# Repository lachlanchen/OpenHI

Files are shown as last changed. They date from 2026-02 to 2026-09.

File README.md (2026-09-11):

[English](README.md) · [العربية](i18n/README.ar.md) · [Español](i18n/README.es.md) · [Français](i18n/README.fr.md) · [日本語](i18n/README.ja.md) · [한국어](i18n/README.ko.md) · [Tiếng Việt](i18n/README.vi.md) · [中文 (简体)](i18n/README.zh-Hans.md) · [中文（繁體）](i18n/README.zh-Hant.md) · [Deutsch](i18n/README.de.md) · [Русский](i18n/README.ru.md)

# Self-Calibrated Neuromorphic Hyperspectral Imaging (OpenHI)















> [!NOTE]
> i18n status in this checkout: all linked translation files are present under `i18n/` (`ar`, `de`, `es`, `fr`, `ja`, `ko`, `ru`, `vi`, `zh-Hans`, `zh-Hant`) with English as the root canonical README.

A comprehensive pipeline for reconstructing spectra from event cameras with dispersed light illumination (e.g., diffraction grating). The system records intensity change events $e = (x, y, t, p)$ where $p \in \{-1, +1\}$ indicates polarity of log-intensity change, and automatically infers scan timing and calibration metadata ("auto info") directly from the event stream.

> [!IMPORTANT]
> This README is the canonical technical source for the repository root. Localized files under `i18n/` should mirror section and header evolution while keeping exactly one language-options line at the top.

<p align="center">
  Device setup
  Acquisition GUI
</p>

*Left: modular transmission microscope with a motorised grating illumination arm and vertical detection stack. Right: data-acquisition GUI used to monitor segmentation, compensation, and reconstructions in real time.*

## Quick Access

| Need | Jump to |
|---|---|
| Start in ~5 minutes | [Quick Start (5-Min Path) ⚡](#quick-start-5-min-path) |
| Run the full pipeline wrapper | [`scripts/run_scan_pipeline.sh`](scripts/run_scan_pipeline.sh) |
| Understand script flow | [Overview 🔭](#overview), [Core Scripts 🧠](#core-scripts) |
| Tune parameters | [Configuration 🎛️](#configuration), [Configuration Examples 🧩](#configuration-examples) |
| Use GUI tools | [Additional Tools 🛠️](#additional-tools) |
| Hardware docs (BOM, PCB, 3D, firmware) | [Repository Map 🗺️](#repository-map) |
| Inspect a frozen software-stage run | [Fixture, environment, log, output, and hashes](https://lazying.art/openhi-reproducibility/sample-report/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) |
| Test one software stage on your setup | [USD 500 reproducibility sprint](https://lazying.art/openhi-reproducibility/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) |
| Multilingual maintenance rules | [Internationalization 🌍](#internationalization) |
| Sponsor and support links | [Support / Sponsor 💖](#support--sponsor) |

## At a Glance

| Item | Details |
|---|---|
| Core idea | Self-calibrated hyperspectral derivative imaging from event streams |
| Main stages | `segment_robust_fixed.py` -> `compensate_multiwindow_train_saved_params.py` -> visualization scripts |
| Hardware docs in repo | `3D/`, `PCB/`, `firmware/`, `BOM/` |
| Desktop tools | `scan_compensation_gui_cloud.py`, `ImagingGUI/DualCamera_separate_transform.py` |
| Canonical paper | [Optica article (DOI: 10.1364/OPTICA.585766)](https://doi.org/10.1364/OPTICA.585766) |
| i18n in this checkout | `README.ar.md`, `README.de.md`, `README.es.md`, `README.fr.md`, `README.ja.md`, `README.ko.md`, `README.ru.md`, `README.vi.md`, `README.zh-Hans.md`, `README.zh-Hant.md` |

### Compatibility Snapshot

| Area | Current repository reality |
|---|---|
| Python baseline | `3.9+` recommended (some `ImagingGUI/` utilities note `3.10+`) |
| Main pipeline launcher | `scripts/run_scan_pipeline.sh` |
| Core training script | `compensate_multiwindow_train_saved_params.py` |
| Hardware collateral | Present under `3D/`, `PCB/`, `BOM/`, `firmware/` |
| Multilingual docs | `i18n/` contains all 10 linked language files |

> [!TIP]
> Ask about the core development kit (excluding camera, tube lens, and optical table) for the paper [Self-calibrated neuromorphic hyperspectral derivative imaging](https://doi.org/10.1364/OPTICA.585766) published in Optica:
> - https://lazying.art/openhi-kit.html
>
> Evaluating the software first? The [OpenHI Software Reproducibility Sprint](https://lazying.art/openhi-reproducibility/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) tests one named pipeline stage on one existing workstation and rights-cleared dataset before a hardware decision.

## Contents

- [Quick Access ⚡](#quick-access)
- [At a Glance 📌](#at-a-glance)
- [Overview 🔭](#overview)
- [Features ✨](#features)
- [Repository Map 🗺️](#repository-map)
- [Project Structure 📁](#project-structure)
- [Quick Start (5-Min Path) ⚡](#quick-start-5-min-path)
- [Prerequisites 🧰](#prerequisites)
- [Installation ⚙️](#installation)
- [Usage 🚀](#usage)
- [Internationalization 🌍](#internationalization)
- [Configuration 🎛️](#configuration)
- [Examples 🧪](#examples)
- [Bill of Materials (Core Module) 🧾](#bill-of-materials-core-module)
- [Core Scripts 🧠](#core-scripts)
- [Additional Tools 🛠️](#additional-tools)
- [Turbo Multi-Scan Compensation ⚡](#turbo-multi-scan-compensation)
- [Parameter Management 💾](#parameter-management)
- [Memory Optimization 🧱](#memory-optimization)
- [Output Structure 📦](#output-structure)
- [Configuration Examples 🧩](#configuration-examples)
- [Wavelength Mapping 🌈](#wavelength-mapping)
- [Tips and Best Practices ✅](#tips-and-best-practices)
- [Development Notes 🧭](#development-notes)
- [Troubleshooting 🩺](#troubleshooting)
- [Roadmap 🛣️](#roadmap)
- [Citation 📎](#citation)
- [Acknowledgements 🙏](#acknowledgements)
- [License 📄](#license)
- [Contributing 🤝](#contributing)
- [Support / Sponsor 💖](#support--sponsor)

## Overview

When illumination sweeps across wavelengths over time, the event stream encodes a temporal derivative of the underlying spectrum along the dispersion axis.

```text
RAW event recording
   -> scan timing segmentation (F/B passes)
   -> multi-window time-warp compensation
   -> frame/cumulative/wavelength diagnostics
```

This pipeline provides three main stages:

| Stage | Purpose | Primary script(s) |
|---|---|---|
| 1. Segment | Find scan timing and split recordings into forward/backward passes | `segment_robust_fixed.py` |
| 2. Compensate | Estimate piecewise-linear time-warp to remove scan-induced temporal tilt | `compensate_multiwindow_train_saved_params.py` |
| 3. Visualize | Overlay learned boundaries and compare original vs. compensated time-binned frames | `visualize_boundaries_and_frames.py`, `visualize_cumulative_compare.py` |

The repository also includes hardware assets, acquisition GUI code, and archival experiment branches under `versions/`.

### Pipeline Legend

| Icon | Meaning |
|---|---|
| 🧩 | Segmentation and scan splitting |
| 🧠 | Compensation and parameter learning |
| 🖼️ | Visual diagnostics and output inspection |
| 🌈 | Wavelength mapping and spectral rendering |

### Scope and Assumptions

- This repository is research-oriented and includes active scripts plus archival experiments and results.
- Commands in this README assume execution from repository root unless otherwise noted.
- Several optional workflows depend on external SDKs and local datasets that are not bundled here.
- If a command mentions a historical path that no longer exists, prefer the updated root scripts and comparisons paths documented in this README.

## Features

- End-to-end RAW-to-spectrum event processing workflow.
- Auto/manual scan period detection and forward/backward segmentation.
- Multi-window compensation with trainable/fixed parameter modes.
- Parameter save/load in `NPZ`, `JSON`, and `CSV`.
- Multi-scan merge workflow for faster training iterations (`compensate_multiwindow_turbo.py`).
- Visualization suite for boundaries, binned frames, cumulative curves, and weighted diagnostics.
- Hardware documentation: BOM, PCB, 3D parts, firmware notes.
- Acquisition utilities for synchronized event/frame camera setups.

| Category | Included capabilities |
|---|---|
| Signal processing | Segmentation, period detection, time-warp compensation |
| Optimization | Trainable/fixed parameters, smoothness controls, chunked training |
| Outputs | Visual overlays, cumulative comparisons, wavelength-mapped diagnostics |
| Platform assets | Hardware design files, firmware notes, GUI tooling, historical archives |

## Repository Map

Key hardware assets are kept alongside the code for quick access:

| Area | Path |
|---|---|
| 3D-printed parts | [`3D/`](3D/) |
| PCB layouts | [`PCB/`](PCB/) |
| Microcontroller firmware | [`firmware/`](firmware/) |
| Acquisition UI (desktop) | [`ImagingGUI/`](ImagingGUI/) |
| Experiment/data references | [`comparisons/reference_spectrum_2835/`](comparisons/reference_spectrum_2835/), [`comparisons/reference_spectrum_lumileds/`](comparisons/reference_spectrum_lumileds/), [`references/`](references/) |
| Alignment analysis | [`comparisons/align_background_vs_reference_code/`](comparisons/align_background_vs_reference_code/), [`comparisons/alignment_configs/`](comparisons/alignment_configs/) |

## Project Structure

```text
OpenHI/
├── README.md
├── QUICKSTART.md
├── LICENSE
├── versions.md
├── 3D/
├── BOM/
├── PCB/
├── firmware/
├── ImagingGUI/
├── scripts/
├── segment_robust_fixed.py
├── compensate_multiwindow_train_saved_params.py
├── compensate_multiwindow_turbo.py
├── compensate_multiwindow*.py
├── visualize_boundaries_and_frames.py
├── visualize_cumulative_compare.py
├── visualize_cumulative_weighted.py
├── scan_compensation_gui_cloud.py
├── show_envi_spectrum_gui.py
├── simple_raw_reader.py
├── comparisons/align_background_vs_reference_code/
├── align_data_vs_filter_code/
├── comparisons/alignment_configs/
├── versions/05_archive_code_variants/
├── comparisons/outputs_root/
├── comparisons/reference_filters/
├── comparisons/reference_spectrum_2835/
├── comparisons/reference_spectrum_lumileds/
├── references/
├── i18n/
└── versions/
```

## Quick Start (5-Min Path)

If your environment is already prepared and your dataset folder contains a `*event*.raw` file:

```bash
scripts/run_scan_pipeline.sh /path/to/dataset_dir
```

To force a specific RAW file:

```bash
scripts/run_scan_pipeline.sh /path/to/dataset_dir /path/to/recording_event.raw
```

This wrapper runs segmentation, compensation training, and visualization using repository-default script paths and CLI flags.

> [!TIP]
> For first validation, run the wrapper on one dataset directory, then inspect the generated segment NPZ and visualization outputs before tuning `PIPELINE_*` variables.

## Prerequisites

- Python 3.9+ (Python 3.10+ for some GUI tooling under `ImagingGUI/`).
- Core Python packages: `numpy`, `torch`, `matplotlib`.
- Optional but common: `opencv-python`, `pillow`, `cellpose`.
- Metavision SDK / Python bindings for RAW event reading workflows (`simple_raw_reader.py`, segmentation from RAW).
- CUDA-enabled PyTorch is recommended for faster optimization.
- RAW recordings and/or segmented NPZ files available locally.

## Installation

No locked environment file is currently provided at repository root. Suggested setup:

```bash
# create and activate a virtual environment or conda env
python -m venv .venv
source .venv/bin/activate

# install core dependencies
pip install numpy matplotlib torch

# optional tools often used in this repository
pip install opencv-python pillow
# pip install cellpose
```

If using Git hooks for large-file hygiene:

```bash
bash scripts/setup_hooks.sh
```

Recommended quick sanity checks:

```bash
python -c "import numpy, torch, matplotlib; print('core deps ok')"
python -c "import torch; print('cuda:', torch.cuda.is_available())"
```

## Usage

### Basic Workflow (current root scripts)

```bash
# 1. Segment RAW into 6 scans (Forward/Backward)
python segment_robust_fixed.py \
  data/recording.raw \
  --segment_events \
  --output_dir data/segments/

# 2. Train multi-window compensation
python compensate_multiwindow_train_saved_params.py \
  data/segments/Scan_1_Forward_events.npz \
  --bin_width 50000 \
  --visualize --plot_params --a_trainable \
  --iterations 1000

# 3. Visualize results with boundaries
python visualize_boundaries_and_frames.py \
  data/segments/Scan_1_Forward_events.npz

# 4. Compare cumulative vs multi-bin means
python visualize_cumulative_compare.py \
  data/segments/Scan_1_Forward_events.npz \
  --sensor_width 1280 --sensor_height 720
```

### One-command convenience wrapper

```bash
scripts/run_scan_pipeline.sh /path/to/dataset_dir [raw_file]
```

### Command-to-Output Reference

| Step | Command entrypoint | Primary output |
|---|---|---|
| Segment scans | `segment_robust_fixed.py` | `*_segments/Scan_*_{Forward,Backward}_events.npz` |
| Train compensation | `compensate_multiwindow_train_saved_params.py` | `*learned_params_n*.{npz,json,csv}` plus diagnostics |
| Boundary and frame diagnostics | `visualize_boundaries_and_frames.py` | timestamped visualization folder with overlays and bins |
| Cumulative diagnostics | `visualize_cumulative_compare.py`, `visualize_cumulative_weighted.py` | cumulative and statistical plots for scan quality checks |
| Convenience wrapper | `scripts/run_scan_pipeline.sh` | end-to-end segmentation, training, and visualization |

### Minimal Smoke Test

Use this when you want to validate script wiring on an existing segment NPZ before a longer optimization run:

```bash
python visualize_boundaries_and_frames.py /path/to/Scan_1_Forward_events.npz \
  --sample_rate 0.05 --sensor_width 1280 --sensor_height 720

python visualize_cumulative_compare.py /path/to/Scan_1_Forward_events.npz \
  --sensor_width 1280 --sensor_height 720
```

Environment knobs supported by `scripts/run_scan_pipeline.sh`:

| Variable | Default | Purpose |
|---|---:|---|
| `PIPELINE_ACTIVITY_FRACTION` | `0.90` | Active event window fraction |
| `PIPELINE_BIN_WIDTH` | `50000` | Training bin width in microseconds |
| `PIPELINE_SENSOR_WIDTH` | `1280` | Sensor width for visualization |
| `PIPELINE_SENSOR_HEIGHT` | `720` | Sensor height for visualization |
| `PIPELINE_SAMPLE_RATE` | `0.10` | Event sampling fraction for plotting |
| `PIPELINE_TIME_BIN_US` | `1000` | Segmentation activity-bin size |
| `PIPELINE_SEGMENT_PATTERN` | `Scan_1_Forward_events.npz` | Segment file pattern for downstream scripts |

## Internationalization

The repository uses a single language-options line at the top of each README to avoid duplicated language bars.

Currently available translated files in `i18n/`:

- `README.ar.md`
- `README.es.md`
- `README.fr.md`
- `README.ja.md`
- `README.ko.md`

| Language link in nav | File in `i18n/` | Status |
|---|---|---|

Planned language links are intentionally preserved in the top navigation for forward compatibility.

## Configuration

Important CLI controls used across scripts:

### Segmentation (`segment_robust_fixed.py`)

- `--time_bin_us`: activity bin size in microseconds.
- `--round_trip_period`: manual period (default `1688` bins).
- `--auto_calculate_period`: period via autocorrelation.
- `--activity_fraction`: active event window fraction.
- `--manual_start_shift_ms`: manual scan start offset.

### Compensation (`compensate_multiwindow_train_saved_params.py`)

- `--num_params` (default `13`), `--temperature` (default `5000`).
- `--a_trainable` / `--a_fixed`, `--b_trainable` / `--b_fixed`, `--boundary_trainable`.
- `--a_default`, `--b_default`.
- `--iterations`, `--learning_rate`, `--smoothness_weight`.
- `--chunk_size` for memory control.
- `--load_params` to reuse learned parameters.

### Visualization

- `visualize_boundaries_and_frames.py`: `--sample_rate`, `--wavelength_min`, `--wavelength_max`, sensor size args.
- `visualize_cumulative_compare.py`: sensor size, `--output_dir`, `--sample_label`.
- `visualize_cumulative_weighted.py`: polarity scales, `--step_us`, `--auto_scale`, `--exp`, `--no_comp`.

## Examples

### Quick start dataset-style commands (from `QUICKSTART.md`)

```bash
python segment_robust_fixed.py \
  led_12v_no_acc_glass/glass/sync_recording_12v_led_no_acc_blank_event_20250804_232556.raw \
  --segment_events \
  --output_dir led_12v_no_acc_glass/glass/

python compensate_multiwindow_train_saved_params.py \
  led_12v_no_acc_glass/glass/sync_recording_12v_led_no_acc_blank_event_20250804_232556_segments/Scan_1_Forward_events.npz \
  --bin_width 50000 \
  --visualize --plot_params --a_trainable \
  --iterations 1000 \
  --b_default 0 \
  --smoothness_weight 0.001

python visualize_boundaries_and_frames.py \
  led_12v_no_acc_glass/glass/sync_recording_12v_led_no_acc_blank_event_20250804_232556_segments/Scan_1_Forward_events.npz
```

### Legacy helper commands retained from historical workflows

```bash
python scanning_alignment_visualization_save.py \
  led_12v_no_acc_glass/glass/sync_recording_12v_led_no_acc_blank_event_20250804_232556_segments/Scan_1_Forward_events.npz \
  --output_dir led_12v_no_acc_glass/glass/sync_recording_12v_led_no_acc_blank_event_20250804_232556_segments/FIXED_visualization

python scanning_alignment_visualization_cumulative_compare.py \
  led_12v_no_acc_glass/glass/sync_recording_12v_led_no_acc_blank_event_20250804_232556_segments/Scan_1_Forward_events.npz \
  --sensor_width 1280 --sensor_height 720 \
  --output_dir led_12v_no_acc_glass/glass/sync_recording_12v_led_no_acc_blank_event_20250804_232556_segments/cumulative_vs_bin2ms \
  --sample_label "led_12v_no_acc_glass Scan_1_Forward"
```

These legacy commands are intentionally preserved for compatibility context; in this checkout, use current root scripts where possible.

### Turbo multi-scan training

```bash
python compensate_multiwindow_turbo.py \
  --segments-dir path/to/your_segments \
  --include all --sort name \
  --bin-width 5000 \
  -- --a_trainable --iterations 1000 --smoothness_weight 0.001 --chunk_size 250000 --visualize --plot_params
```

### Reuse learned parameters (skip retraining)

```bash
python compensate_multiwindow_train_saved_params.py segment.npz \
  --load_params learned_params.npz
```

## Bill of Materials (Core Module)

See [`BOM/core_module.md`](BOM/core_module.md) for the full table with links and notes.

### Table S2. Acquisition Time and Cost Comparison Between the Proposed Event-Driven System and a Reference Hyperspectral Camera

| Parameter | Ours | Reference camera |
|---|---|---|
| Acquisition time | ∼585 ms per scan | 300 s per scan |
| Data volume | 18.5 MB | 138 MB |
| Approx. price | ∼3000 USD | 14 000 USD |

### Table S3. Bill of Materials for the Core Scanning Illumination Module
(Excluding event camera and optional 4f validation optics)

| Component | Notes | Cost (USD) | Taobao Link |
|---|---|---:|---|
| Motion control | NEMA42 + TB6600 + Arduino Uno | 15.00 | https://e.tb.cn/h.7FHgkEvoo6tpKTo?tk=QYRFUPRqazE |
| Optics (grating) | Diffraction grating (education grade) | 3.47 | https://e.tb.cn/h.7Fhj16MkrSDHNnE?tk=3Q8dUPRouNw |
| Illumination | 2835 LED (6 CNY / 10 pcs; 0.6 CNY used) | 0.08 | https://e.tb.cn/h.7uubHIVL5diILHl?tk=tzTAUPRr14K |
| Reflector | Folding mirror | 6.25 | https://e.tb.cn/h.7uu1rNNSbgVdS31?tk=PqsxUPRHb32 |
| Electronics | LED PCB (CNY/board; min order 5 pcs) | 1.67 |  |
| Limit switches | Optional, 2 × 8.07 CNY | 2.24 | https://e.tb.cn/h.7FHEKbcgJmc2Ll1?tk=I4FRUP8diRE |
| 3D printing | One-third PLA filament spool (covers all printed parts) | 5.09 | https://e.tb.cn/h.7FhOVWX7SLHvNNf?tk=kOcQUPRJsbo |
| Lens | Plano-convex lens (25.4 mm, 350–700 nm AR) |  | https://e.tb.cn/h.7FSePNYhqt7ITbh?tk=tH8ZUP8i3cC |
| Total | core module | **33.99** |  |

## Core Scripts

### 1. Segmentation: `segment_robust_fixed.py`

**Goal**: Extract scan timing from raw events and slice into 6 one-way scans (F, B, F, B, F, B).

**Mathematical Description**:

- **Activity signal** (events binned with $\Delta t = 1000~\mu\text{s}$):
  $$a[n] = \left|\{ i \mid t_{\min} + n\Delta t \le t_i < t_{\min} + (n+1)\Delta t \}\right|.$$

- **Active window detection**: find the smallest contiguous window containing $80\%$ of events.

- **Period estimation**: autocorrelation or manual period (default: $1688$ bins).

- **Reverse-correlation** (timing structure):
  $$R[k] = \sum_{n} a[n]\, a_{\text{rev}}[n+k]$$
  with
  $$a_{\text{rev}}[n] = a[N-1-n].$$

**Usage**:

```bash
# Automatic period detection
python segment_robust_fixed.py recording.raw --segment_events --output_dir segments/

# Manual period (fixed 1688 bins)
python segment_robust_fixed.py recording.raw --segment_events --round_trip_period 1688
```

**Arguments**:

- `--segment_events`: Save individual scan segments as NPZ files.
- `--round_trip_period 1688`: Use manual period (default).
- `--auto_calculate_period`: Override manual period with autocorrelation.
- `--activity_fraction 0.80`: Fraction of events for active region.
- `--max_iterations 2`: Refinement iterations.

### 2. Compensation: `compensate_multiwindow_train_saved_params.py`

**Goal**: Learn time-warp parameters to remove scan-induced temporal shear using multi-window piecewise-linear compensation.

**Mathematical Description**:

- **Boundary surfaces**:
  $$T_i(x, y) = a_i x + b_i y + c_i,\quad i=0,\ldots,M-1.$$

- **Soft window memberships**:
  $$m_i = \sigma\!\Big(\frac{t - T_i}{\tau}\Big)\,\sigma\!\Big(\frac{T_{i+1} - t}{\tau}\Big),\qquad w_i = \frac{m_i}{\sum_j m_j + \varepsilon}.$$

- **Interpolated slopes (optional)**:
  $$\alpha_i = \frac{t - T_i}{T_{i+1} - T_i},\quad a_i' = (1-\alpha_i)a_i + \alpha_i a_{i+1},\quad b_i' = (1-\alpha_i)b_i + \alpha_i b_{i+1}.$$

- **Time warp**:
  $$\Delta t(x,y,t) = \sum_i w_i (\tilde{a}_i x + \tilde{b}_i y),\qquad t' = t - \Delta t(x,y,t).$$

- **Loss**: variance minimization of time-binned frames with smoothness regularization on parameters.

**Usage**:

```bash
# Train with a-parameters trainable, b fixed
python compensate_multiwindow_train_saved_params.py segment.npz \
  --bin_width 50000 --a_trainable --b_default -76.0 \
  --iterations 1000 --smoothness_weight 0.001

# Load pre-trained parameters
python compensate_multiwindow_train_saved_params.py segment.npz \
  --load_params learned_params.npz
```

**Key Arguments**:

- `--a_trainable` / `--a_fixed`: Control a-parameter training (default: fixed).
- `--b_trainable` / `--b_fixed`: Control b-parameter training (default: trainable).
- `--num_params 13`: Number of boundary parameters.
- `--temperature 5000`: Sigmoid temperature for soft windows.
- `--smoothness_weight 0.001`: Regularization weight.
- `--load_params file.npz`: Load saved parameters.
- `--chunk_size 250000`: Memory-efficient processing chunk size.

### 3. Visualization: `visualize_boundaries_and_frames.py`

**Goal**: Display learned parameters and show qualitative improvements.

**Features**:

- Parameter overlays on $x\text{–}t$ and $y\text{–}t$ projections.
- Time-binned frame comparisons (original vs. compensated).
- Sliding window analysis (50 ms and 2 ms bins).
- Wavelength mapping for spectral visualization.

**Usage**:

```bash
python visualize_boundaries_and_frames.py segment.npz \
  --sample_rate 0.1 --wavelength_min 380 --wavelength_max 680
```

### 4. Cumulative Comparison: `visualize_cumulative_compare.py`

**Goal**: Compare cumulative 2 ms-step means with sliding bin means.

**Mathematical Description**:

- **Cumulative means**:
  $$F(T) = \frac{1}{HW}\sum_{t < T}\text{events}(t).$$

- **Sliding means**: event counts in $[T-\Delta,\,T)$ divided by $H \times W$.

- **Relationship** (finite-difference derivative):
  $$\Delta F(T) \approx \frac{F(T) - F(T-\Delta)}{\Delta}.$$

**Usage**:

```bash
python visualize_cumulative_compare.py segment.npz \
  --sensor_width 1280 --sensor_height 720 \
  --sample_label "My Dataset"
```

## Additional Tools

### GUI Application: `scan_compensation_gui_cloud.py`

Complete GUI for scan compensation with 3D spectral visualization.

**Features**:

- Interactive parameter tuning.
- Real-time optimization progress.
- 3D wavelength-mapped visualization.
- Export results and parameters.

**Usage**:

```bash
python scan_compensation_gui_cloud.py
```

### Dual Camera System (current path)

Synchronized recording system for event and frame cameras:

- `ImagingGUI/DualCamera_separate_transform.py`

**Features**:

- Simultaneous event and frame recording.
- Real-time preview with transformations.
- Always-on-top window controls.
- Parameter adjustment during recording.

### Arduino Motor Control (legacy path reference retained)

The original README referenced this firmware sketch path:

- `rotor/step42_with_key_int/step42_with_key_int.ino`

Current repository layout includes firmware notes at:

- `firmware/README.md`

This path mismatch is preserved here intentionally; if you have the rotor sketch folders in another branch/local checkout, keep using those paths.

Legacy documented capabilities of this sketch include:

- Precise angle control with microstepping.
- Acceleration/deceleration profiles.
- Limit switch integration.
- Auto-centering functionality.

## Turbo Multi-Scan Compensation

When you have multiple one-way scans (Forward/Backward) of the same sweep, you can merge them and run the proven trainer on a single combined event stream using `compensate_multiwindow_turbo.py`.

### What it does

- Accepts one segment, an explicit list, or a whole segments directory.
- For Backward scans, flips polarity and reverses time before merging:
- If polarity `p ∈ {0,1}`: `p := 1 − p`; then reverse time within the scan.
- If polarity `p ∈ {−1,1}`: `p := −p`; then reverse time within the scan.
- Concatenates scans on a continuous timeline (with a `1 μs` gap between scans) and calls `compensate_multiwindow_train_saved_params.py` under the hood.

### Usage

```bash
# Merge all scans (Forward+Backward) from a segments folder and train at 5 ms
python compensate_multiwindow_turbo.py \
  --segments-dir path/to/.../_segments \
  --include all --sort name \
  --bin-width 5000 \
  -- --a_trainable --iterations 1000 --smoothness_weight 0.001 --chunk_size 250000 --visualize --plot_params

# Reuse learned params and just render at 10 ms (fast, no training)
python compensate_multiwindow_turbo.py \
  --segments-dir path/to/.../_segments \
  --include all --sort time \
  --bin-width 10000 \
  --load-params path/to/learned_params.npz \
  -- --visualize --plot_params

# Only Forward scans
python compensate_multiwindow_turbo.py \
  --segments-dir path/to/.../_segments \
  --include forward --sort time \
  --bin-width 5000 \
  -- --a_trainable --iterations 1000 --smoothness_weight 0.001 --chunk_size 250000
```

### Options

- `--segment`, `--segments`, `--segments-dir`: choose your input set.
- `--include {all|forward|backward}`: filter by scan direction.
- `--sort {name|time}`: natural filename order or NPZ `start_time` order.
- `--bin-width <μs>`: forwarded to the base trainer.
- `--load-params`: reuse saved parameters (skip training and regenerate outputs quickly at new bin widths).
- `--extra ...` after `--`: any additional flags are forwarded to the base trainer.

### Speed scaling tip

If your scan is `N×` faster than baseline, reduce `--bin-width` by the same factor (e.g., baseline `50 ms` -> `10×` faster -> `5 ms`: `--bin-width 5000`). You can train once (e.g., `5 ms`), then use `--load-params` to quickly regenerate results at `10 ms` without retraining.

## Parameter Management

The system supports comprehensive parameter save/load functionality.

### Save Formats

- **NPZ**: Binary format for fast loading.
- **JSON**: Human-readable with metadata.
- **CSV**: Excel-compatible for manual inspection.

### Parameter Loading

```bash
# Load any supported format
python compensate_multiwindow_train_saved_params.py segment.npz \
  --load_params learned_params.npz
# or --load_params learned_params.json
# or --load_params learned_params.csv
```

### Parameter Files

Files are automatically named with parameter count, such as: `*_learned_params_n13.*`.

## Memory Optimization

The system uses chunked processing throughout:

| Item | Detail |
|---|---|
| Chunk Size | Default `250000` events (configurable) |
| Memory Efficient | Processes large datasets without GPU overflow |
| Unified Variance | Maintains proper gradient flow for learning |
| Progress Tracking | Real-time processing updates |

## Output Structure

```text
project/
├── data/
│   ├── recording.raw                    # Original RAW file
│   ├── recording_segments/              # Segmented scans
│   │   ├── Scan_1_Forward_events.npz
│   │   ├── Scan_2_Backward_events.npz
│   │   └── ...
│   ├── learned_params_n13.npz          # Trained parameters
│   ├── learned_params_n13.json
│   ├── learned_params_n13.csv
│   └── visualization_20240115_143022/  # Results
│       ├── events_with_params.png
│       ├── sliding_frames_*.npz
│       ├── frame_means_wavelength.png
│       └── time_binned_frames/         # Individual frames
```

## Configuration Examples

### High-Precision Compensation

```bash
python compensate_multiwindow_train_saved_params.py segment.npz \
  --num_params 21 --temperature 3000 --iterations 2000 \
  --a_trainable --b_trainable --boundary_trainable \
  --smoothness_weight 0.0001 --chunk_size 100000
```

### Fast Processing

```bash
python compensate_multiwindow_train_saved_params.py segment.npz \
  --num_params 7 --iterations 500 --chunk_size 500000 \
  --a_fixed --b_default -76.0
```

### Memory Constrained

```bash
python compensate_multiwindow_train_saved_params.py segment.npz \
  --chunk_size 50000 --bin_width 100000
```

## Wavelength Mapping

The system supports spectral visualization by mapping temporal evolution to wavelength:

```python
# Linear mapping: time -> wavelength
wavelength = wavelength_min + (t_normalized / t_max) * (wavelength_max - wavelength_min)
```

**Default Range**: $380\text{–}680~\text{nm}$ (configurable).

## Tips and Best Practices

### Parameter Selection

- **Microstepping**: Use `32×` for smooth motion (Arduino).
- **Bin Width**: Start with `50 ms` for optimization, `2 ms` for analysis.
- **Temperature**: Higher values (around `5000`) for smoother boundaries.
- **Smoothness**: `0.001` provides good regularization.

### Memory Management

- **GPU Memory**: Use chunked processing with appropriate chunk size.
- **Event Count**: `> 10^6` events recommended for stable learning.
- **Iterations**: `1000` iterations usually sufficient.

### File Organization

- Keep RAW files and segments in the same directory.
- Parameter files are auto-detected by naming convention.
- Use descriptive filename prefixes for organized output.

## Development Notes

- `versions.md` describes historical project eras and migration rationale.
- `.githooks/pre-commit` blocks oversized/binary commits and non-code/doc file types.
- `scripts/setup_hooks.sh` sets `core.hooksPath` to `.githooks`.
- `versions/05_archive_code_variants/` stores older script variants to keep root-level tooling focused.

Known documentation drift (preserved intentionally for backward compatibility context):

- Some older docs mention `sync_image_system/` or `dual_camera_gui.py`; current checkout contains `ImagingGUI/DualCamera_separate_transform.py` and SDK directories.
- `ImagingGUI/README.md` still references `pip install -r requirements.txt`, but no root `requirements.txt` is present in this checkout.
- `firmware/README.md` references several Arduino sketch subfolders that are not present in this checkout.
- `versions.md` mentions legacy script names that differ from current root-level script names.
- `i18n/` exists and currently includes `README.ar.md`, `README.es.md`, `README.fr.md`, `README.ja.md`, and `README.ko.md`; links for additional languages are retained as planned targets.

## Troubleshooting

| Symptom | Likely cause | Action |
|---|---|---|
| Parameter loading errors | Parameter count mismatch | Ensure `--num_params` matches the saved file |
| OOM / memory pressure | Chunk too large or bins too fine | Reduce `--chunk_size` and/or increase `--bin_width` |
| Weak compensation quality | Under-trained or poor segmentation | Increase `--iterations`, enable trainable params, verify segmentation |
| No segment files produced | RAW/SDK/flag issue | Confirm RAW path, Metavision setup, and `--segment_events` |
| Turbo wrapper args ignored | Incorrect forwarding syntax | Pass trainer args after `--` (or use `--extra`) |
| GUI issues | Tkinter/backend or SDK mismatch | Verify GUI backend and camera SDK availability |

- **Parameter loading errors**: Ensure `--num_params` is compatible with the loaded parameter file.
- **OOM / memory pressure**: Reduce `--chunk_size` and/or increase `--bin_width`.
- **Weak compensation quality**: Increase `--iterations`, enable trainable parameters (`--a_trainable`, `--b_trainable`, optionally `--boundary_trainable`), and verify segmentation quality.
- **No segment files produced**: Confirm RAW path, Metavision reader availability, and that `--segment_events` was passed.
- **Turbo wrapper argument passing**: Put trainer args after `--` (or use `--extra`).
- **GUI issues**: Verify Tkinter backend support and camera SDK availability on your platform.

## Roadmap

- Improve dependency/bootstrap reproducibility (`requirements.txt` or environment lockfile).
- Consolidate legacy script names and path references across docs.
- Expand documented dataset schemas and expected NPZ field conventions.
- Add regression-style tests for segmentation/compensation on small fixture data.
- Continue integrating publication-quality analysis outputs from `align_*` pipelines.
- Add/refresh the remaining multilingual README files under `i18n/` to fully match the language navigation links at top.

## Citation

If this repository is useful in your research, please cite the Optica article:

```bibtex
@article{chen2026self,
  title   = {Self-calibrated neuromorphic hyperspectral derivative imaging},
  author  = {Chen, Rongzhou and Wang, Chutian and Li, Yuxing and Cao, Yuqing and Zhu, Shuo and Lam, Edmund Y},
  journal = {Optica},
  volume  = {13},
  number  = {4},
  pages   = {587--590},
  year    = {2026},
  publisher = {Optica Publishing Group},
  doi     = {10.1364/OPTICA.585766},
  url     = {https://doi.org/10.1364/OPTICA.585766}
}
```

## Acknowledgements

- Published Optica article and associated project dissemination materials.
- Hardware and software contributors across repository evolution captured in `versions/` and archived tooling.
- Community support through GitHub Sponsors and associated project channels.

## License

This project is released under the MIT License. See [`LICENSE`](LICENSE) for details.

## Contributing

Contributions are welcome.

- Start with existing scripts and documentation style.
- Keep command-line examples reproducible with repository paths where possible.
- If you add large datasets/outputs, ensure `.githooks/pre-commit` policies are respected.

Note: a dedicated `CONTRIBUTING.md` is not present in this checkout. If needed, open an issue or submit a PR with the contribution workflow you propose.

## ❤️ Support

If this project is useful to you, these links directly support ongoing maintenance and hardware iteration.

| Donate | PayPal | Stripe |
|---|---|---|
| Donate (https://chat.lazying.art/donate) | PayPal (https://paypal.me/RongzhouChen) | Stripe (https://buy.stripe.com/aFadR8gIaflgfQV6T4fw400) |

Need help reproducing one software stage before committing to hardware? See the [fixed USD 500 OpenHI Software Reproducibility Sprint](https://lazying.art/openhi-reproducibility/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). It begins with a free fit check.

---

### Notes

- 📌 This README keeps legacy-path notes where repository evolution introduced naming/layout drift.
- 🔒 If uncertain about older references, the text is preserved intentionally rather than removed.

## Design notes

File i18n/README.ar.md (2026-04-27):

[English](../README.md) · [العربية](README.ar.md) · [Español](README.es.md) · [Français](README.fr.md) · [日本語](README.ja.md) · [한국어](README.ko.md) · [Tiếng Việt](README.vi.md) · [中文 (简体)](README.zh-Hans.md) · [中文（繁體）](README.zh-Hant.md) · [Deutsch](README.de.md) · [Русский](README.ru.md)

# التصوير الطيفي فائق الدقة العصبي ذاتي المعايرة (OpenHI)

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

> [!NOTE]
> حالة i18n في هذا الإصدار المحلي: جميع ملفات الترجمة المرتبطة موجودة ضمن `i18n/` (`ar`, `de`, `es`, `fr`, `ja`, `ko`, `ru`, `vi`, `zh-Hans`, `zh-Hant`) مع اعتماد الإنجليزية كملف README مرجعي أساسي.

مسار عمل شامل لإعادة بناء الأطياف من كاميرات الأحداث تحت إضاءة ضوئية مشتتة (مثل محزوز حيود). يسجّل النظام أحداث تغيّر الشدة بالشكل $e = (x, y, t, p)$ حيث $p \in \{-1, +1\}$ يعبّر عن قطبية تغيّر لوغاريتم الشدة، كما يستنتج تلقائيًا توقيت المسح وبيانات المعايرة الوصفية ("auto info") مباشرةً من تيار الأحداث.

> [!IMPORTANT]
> هذا README هو المصدر التقني المرجعي في جذر المستودع. يجب أن تعكس الملفات المحلية تحت `i18n/` تطور الأقسام/العناوين، مع سطر واحد فقط لخيارات اللغة في الأعلى (من دون تكرار شريط اللغات).

<p align="center">
  Device setup
  Acquisition GUI
</p>

*يسارًا: مجهر نفاذية معياري مع ذراع إضاءة بمحزوز متحرك آليًا ومكدس كشف عمودي. يمينًا: واجهة جمع بيانات لمراقبة التقسيم والتعويض وإعادة البناء في الزمن الحقيقي.*

## Quick Access

| الحاجة | الانتقال السريع |
|---|---|
| بدء التشغيل خلال ~5 دقائق | [Quick Start (5-Min Path) ⚡](#quick-start-5-min-path) |
| تشغيل الغلاف الكامل للمسار | [`scripts/run_scan_pipeline.sh`](../scripts/run_scan_pipeline.sh) |
| فهم تدفق السكربتات | [Overview 🔭](#overview)، [Core Scripts 🧠](#core-scripts) |
| ضبط المعاملات | [Configuration 🎛️](#configuration)، [Configuration Examples 🧩](#configuration-examples) |
| استخدام أدوات GUI | [Additional Tools 🛠️](#additional-tools) |
| توثيق العتاد (BOM/PCB/3D/Firmware) | [Repository Map 🗺️](#repository-map) |
| قواعد صيانة التعدد اللغوي | [Internationalization 🌍](#internationalization) |
| روابط الدعم/الرعاية | [Support / Sponsor 💖](#support--sponsor) |

## At a Glance

| العنصر | التفاصيل |
|---|---|
| الفكرة الأساسية | تصوير طيفي اشتقاقي ذاتي المعايرة من تيارات الأحداث |
| المراحل الرئيسية | `segment_robust_fixed.py` -> `compensate_multiwindow_train_saved_params.py` -> سكربتات التصوّر |
| توثيق العتاد داخل المستودع | `3D/`, `PCB/`, `firmware/`, `BOM/` |
| أدوات سطح المكتب | `scan_compensation_gui_cloud.py`, `ImagingGUI/DualCamera_separate_transform.py` |
| الورقة المرجعية | [مقالة Optica (DOI: 10.1364/OPTICA.585766)](https://doi.org/10.1364/OPTICA.585766) |
| i18n في هذا الإصدار | `README.ar.md`, `README.de.md`, `README.es.md`, `README.fr.md`, `README.ja.md`, `README.ko.md`, `README.ru.md`, `README.vi.md`, `README.zh-Hans.md`, `README.zh-Hant.md` |

### Compatibility Snapshot

| المجال | الواقع الحالي في المستودع |
|---|---|
| خط أساس Python | يوصى بـ `3.9+` (وبعض أدوات `ImagingGUI/` تشير إلى `3.10+`) |
| مشغّل المسار الرئيسي | `scripts/run_scan_pipeline.sh` |
| سكربت التدريب الأساسي | `compensate_multiwindow_train_saved_params.py` |
| أصول العتاد | موجودة ضمن `3D/`, `PCB/`, `BOM/`, `firmware/` |
| التوثيق متعدد اللغات | يحتوي `i18n/` على ملفات اللغات العشر المرتبطة |

> [!TIP]
> اشترِ حزمة التطوير الأساسية (من دون الكاميرا، وعدسة الأنبوب، والطاولة البصرية) الخاصة بورقة [Self-calibrated neuromorphic hyperspectral derivative imaging](https://doi.org/10.1364/OPTICA.585766) المنشورة في Optica:
> - https://lazying.art/openhi-kit.html
> - رمز ترويجي بخصم 30%: `OPTICA`

## Contents

- [Quick Access ⚡](#quick-access)
- [At a Glance 📌](#at-a-glance)
- [Overview 🔭](#overview)
- [Features ✨](#features)
- [Repository Map 🗺️](#repository-map)
- [Project Structure 📁](#project-structure)
- [Quick Start (5-Min Path) ⚡](#quick-start-5-min-path)
- [Prerequisites 🧰](#prerequisites)
- [Installation ⚙️](#installation)
- [Usage 🚀](#usage)
- [Internationalization 🌍](#internationalization)
- [Configuration 🎛️](#configuration)
- [Examples 🧪](#examples)
- [Bill of Materials (Core Module) 🧾](#bill-of-materials-core-module)
- [Core Scripts 🧠](#core-scripts)
- [Additional Tools 🛠️](#additional-tools)
- [Turbo Multi-Scan Compensation ⚡](#turbo-multi-scan-compensation)
- [Parameter Management 💾](#parameter-management)
- [Memory Optimization 🧱](#memory-optimization)
- [Output Structure 📦](#output-structure)
- [Configuration Examples 🧩](#configuration-examples)
- [Wavelength Mapping 🌈](#wavelength-mapping)
- [Tips and Best Practices ✅](#tips-and-best-practices)
- [Development Notes 🧭](#development-notes)
- [Troubleshooting 🩺](#troubleshooting)
- [Roadmap 🛣️](#roadmap)
- [Citation 📎](#citation)
- [Acknowledgements 🙏](#acknowledgements)
- [License 📄](#license)
- [Contributing 🤝](#contributing)
- [Support / Sponsor 💖](#support--sponsor)

> [!IMPORTANT]
> سياسة مصدر المحتوى المرجعي في هذا المستودع: أبقِ `README.md` الإنجليزي في الجذر كمرجع تقني، واعمَل على عكس تطور الأقسام والعناوين في كل ملفات `i18n/README.*.md` مع سطر واحد فقط لخيارات اللغة في الأعلى.

## Overview

عندما تتحرك الإضاءة عبر الأطوال الموجية بمرور الزمن، يشفّر تيار الأحداث مشتقة زمنية من الطيف الكامن على محور التشتت.

```text
RAW event recording
   -> scan timing segmentation (F/B passes)
   -> multi-window time-warp compensation
   -> frame/cumulative/wavelength diagnostics
```

### Pipeline Legend

| الأيقونة | المعنى |
|---|---|
| 🧩 | التقسيم / فصل المسحات |
| 🧠 | التعويض / تعلم المعاملات |
| 🖼️ | تشخيصات مرئية / فحص المخرجات |
| 🌈 | تعيين الأطوال الموجية / التصيير الطيفي |

يوفّر هذا المسار ثلاث مراحل رئيسية:

| المرحلة | الغرض | السكربتات الأساسية |
|---|---|---|
| 1. Segment | اكتشاف توقيت المسح وتقسيم التسجيلات إلى مرور أمامي/خلفي | `segment_robust_fixed.py` |
| 2. Compensate | تقدير تشوّه زمني خطيّ-قطعي لإزالة الميل الزمني الناتج عن المسح | `compensate_multiwindow_train_saved_params.py` |
| 3. Visualize | تراكب الحدود المتعلّمة ومقارنة الإطارات المجمّعة زمنيًا قبل/بعد التعويض | `visualize_boundaries_and_frames.py`, `visualize_cumulative_compare.py` |

يتضمن المستودع أيضًا أصول العتاد، وكود واجهة جمع البيانات، وفروع تجارب مؤرشفة تحت `versions/`.

### Scope and Assumptions

- هذا المستودع موجّه للبحث ويتضمن سكربتات نشطة إضافةً إلى تجارب/نتائج مؤرشفة.
- أوامر هذا README تفترض التنفيذ من جذر المستودع ما لم يُذكر خلاف ذلك.
- بعض المسارات الاختيارية تعتمد على SDK خارجية (Metavision، وحزم SDK لموردي الكاميرات) وبيانات محلية غير مضمّنة في هذا المستودع.
- إذا أشار أمر إلى مسار تاريخي غير موجود، ففضّل سكربتات الجذر المحدّثة المدرجة هنا، مع الإبقاء على الملاحظات القديمة للتوافق الخلفي.

## Features

- سير عمل متكامل لمعالجة الأحداث من RAW إلى طيف.
- كشف فترة المسح تلقائيًا/يدويًا مع التقسيم إلى مرور أمامي وخلفي.
- تعويض متعدد النوافذ مع أوضاع معاملات قابلة للتدريب أو ثابتة.
- حفظ/تحميل المعاملات بصيغ `NPZ`, `JSON`, `CSV`.
- سير دمج متعدد المسحات لتسريع تكرارات التدريب (`compensate_multiwindow_turbo.py`).
- مجموعة تصوّر للحدود والإطارات المجمّعة والمنحنيات التراكمية والتشخيصات الموزونة.
- توثيق عتاد: BOM وPCB وقطع 3D وملاحظات firmware.
- أدوات اقتناء لإعدادات كاميرا أحداث/إطارات متزامنة.

| الفئة | القدرات المتضمنة |
|---|---|
| معالجة الإشارة | التقسيم، كشف الفترة، تعويض التشوّه الزمني |
| التحسين | معاملات قابلة للتدريب/ثابتة، ضوابط النعومة، تدريب مجزّأ |
| المخرجات | تراكبات مرئية، مقارنات تراكمية، تشخيصات مع تعيين للأطوال الموجية |
| أصول المنصة | ملفات تصميم العتاد، ملاحظات firmware، أدوات GUI، أرشيفات تاريخية |

## Repository Map

تُحفَظ أصول العتاد الرئيسية بجانب الشيفرة لتسهيل الوصول السريع:

| المجال | المسار |
|---|---|
| أجزاء مطبوعة ثلاثيًا | [`3D/`](../3D/) |
| مخططات PCB | [`PCB/`](../PCB/) |
| firmware المتحكم الدقيق | [`firmware/`](../firmware/) |
| واجهة جمع البيانات (سطح المكتب) | [`ImagingGUI/`](../ImagingGUI/) |
| مراجع تجريبية/بيانات | [`comparisons/reference_spectrum_2835/`](../comparisons/reference_spectrum_2835/), [`comparisons/reference_spectrum_lumileds/`](../comparisons/reference_spectrum_lumileds/), [`references/`](../references/) |
| تحليل المحاذاة | [`comparisons/align_background_vs_reference_code/`](../comparisons/align_background_vs_reference_code/), [`comparisons/alignment_configs/`](../comparisons/alignment_configs/) |

## Project Structure

```text
OpenHI/
├── README.md
├── QUICKSTART.md
├── LICENSE
├── versions.md
├── 3D/
├── BOM/
├── PCB/
├── firmware/
├── ImagingGUI/
├── scripts/
├── segment_robust_fixed.py
├── compensate_multiwindow_train_saved_params.py
├── compensate_multiwindow_turbo.py
├── compensate_multiwindow*.py
├── visualize_boundaries_and_frames.py
├── visualize_cumulative_compare.py
├── visualize_cumulative_weighted.py
├── scan_compensation_gui_cloud.py
├── show_envi_spectrum_gui.py
├── simple_raw_reader.py
├── comparisons/align_background_vs_reference_code/
├── align_data_vs_filter_code/
├── comparisons/alignment_configs/
├── versions/05_archive_code_variants/
├── comparisons/outputs_root/
├── comparisons/reference_filters/
├── comparisons/reference_spectrum_2835/
├── comparisons/reference_spectrum_lumileds/
├── references/
├── i18n/
└── versions/
```

## Quick Start (5-Min Path)

إذا كانت بيئتك مجهزة مسبقًا وكان مجلد البيانات يحتوي على ملف `*event*.raw`:

```bash
scripts/run_scan_pipeline.sh /path/to/dataset_dir
```

لفرض ملف RAW محدد:

```bash
scripts/run_scan_pipeline.sh /path/to/dataset_dir /path/to/recording_event.raw
```

يشغّل هذا الغلاف التقسيم، وتدريب التعويض، والتصوّر باستخدام مسارات السكربتات الافتراضية في المستودع وخيارات CLI الافتراضية.

> [!TIP]
> للتحقق الأولي، شغّل الغلاف على مجلد بيانات واحد، ثم راجع ملف NPZ الناتج عن التقسيم ومخرجات التصوّر قبل ضبط متغيرات `PIPELINE_*`.

## Prerequisites

- Python 3.9+ (و Python 3.10+ لبعض أدوات GUI داخل `ImagingGUI/`).
- الحزم الأساسية: `numpy`, `torch`, `matplotlib`.
- حزم اختيارية شائعة: `opencv-python`, `pillow`, `cellpose`, `spectral`.
- حزمة اختيارية حسب المنصة: `pywin32` (عادةً لوِرش SDK الكاميرا على Windows).
- Metavision SDK / Python bindings لمسارات قراءة RAW (`simple_raw_reader.py` والتقسيم من RAW).
- يُنصح بـ PyTorch مدعوم CUDA لتسريع التحسين.
- توفر تسجيلات RAW و/أو ملفات NPZ المقسّمة محليًا.

## Installation

لا يوجد ملف بيئة مُقفل في جذر المستودع حاليًا. إعداد مقترح:

```bash
# create and activate a virtual environment or conda env
python -m venv .venv
source .venv/bin/activate

# install core dependencies
pip install numpy matplotlib torch

# optional tools often used in this repository
pip install opencv-python pillow
# pip install cellpose
# pip install spectral pywin32
```

إذا كنت تستخدم Git hooks لضبط الملفات الكبيرة:

```bash
bash scripts/setup_hooks.sh
```

مستحسن (اختياري) لفحوصات قابلية إعادة الإنتاج:

```bash
python -c "import numpy, torch, matplotlib; print('core deps ok')"
python -c "import torch; print('cuda:', torch.cuda.is_available())"
```

## Usage

### Basic Workflow (current root scripts)

```bash
# 1. Segment RAW into 6 scans (Forward/Backward)
python segment_robust_fixed.py \
  data/recording.raw \
  --segment_events \
  --output_dir data/segments/

# 2. Train multi-window compensation
python compensate_multiwindow_train_saved_params.py \
  data/segments/Scan_1_Forward_events.npz \
  --bin_width 50000 \
  --visualize --plot_params --a_trainable \
  --iterations 1000

# 3. Visualize results with boundaries
python visualize_boundaries_and_frames.py \
  data/segments/Scan_1_Forward_events.npz

# 4. Compare cumulative vs multi-bin means
python visualize_cumulative_compare.py \
  data/segments/Scan_1_Forward_events.npz \
  --sensor_width 1280 --sensor_height 720
```

### Command-to-Output Reference

| الخطوة | نقطة تشغيل الأمر | المخرج الأساسي |
|---|---|---|
| Segment scans | `segment_robust_fixed.py` | `*_segments/Scan_*_{Forward,Backward}_events.npz` |
| Train compensation | `compensate_multiwindow_train_saved_params.py` | `*learned_params_n*.{npz,json,csv}` + تشخيصات مرئية |
| Boundary/frame diagnostics | `visualize_boundaries_and_frames.py` | مجلد تصوّر مختوم بالطابع الزمني مع تراكبات وتجميعات |
| Cumulative diagnostics | `visualize_cumulative_compare.py`, `visualize_cumulative_weighted.py` | مخططات تراكمية/إحصائية لفحص جودة المسح |
| Full convenience run | `scripts/run_scan_pipeline.sh` | تقسيم + تدريب + تصوّر من طرف إلى طرف |

### One-command convenience wrapper

```bash
scripts/run_scan_pipeline.sh /path/to/dataset_dir [raw_file]
```

### Minimal Smoke Test (no training changes)

استخدم هذا عندما تريد التحقق سريعًا من ترابط السكربتات على ملف segment NPZ موجود قبل تشغيل تحسين طويل:

```bash
# quick visualization pass
python visualize_boundaries_and_frames.py /path/to/Scan_1_Forward_events.npz \
  --sample_rate 0.05 --sensor_width 1280 --sensor_height 720

# quick cumulative diagnostics
python visualize_cumulative_compare.py /path/to/Scan_1_Forward_events.npz \
  --sensor_width 1280 --sensor_height 720
```

متغيرات البيئة التي يدعمها `scripts/run_scan_pipeline.sh`:

| المتغير | الافتراضي | الغرض |
|---|---:|---|
| `PIPELINE_ACTIVITY_FRACTION` | `0.90` | نسبة نافذة الأحداث النشطة |
| `PIPELINE_BIN_WIDTH` | `50000` | عرض bin للتدريب بالميكروثانية |
| `PIPELINE_SENSOR_WIDTH` | `1280` | عرض الحساس للتصوّر |
| `PIPELINE_SENSOR_HEIGHT` | `720` | ارتفاع الحساس للتصوّر |
| `PIPELINE_SAMPLE_RATE` | `0.10` | نسبة أخذ عينات الأحداث للرسم |
| `PIPELINE_TIME_BIN_US` | `1000` | حجم bin النشاط للتقسيم |
| `PIPELINE_SEGMENT_PATTERN` | `Scan_1_Forward_events.npz` | نمط ملف segment للسكربتات اللاحقة |

### Figure-oriented wrapper (publication workflow)

```bash
scripts/prepare_figure04.sh /path/to/dataset_dir [raw_file]
```

يشغّل هذا الغلاف التقسيم، والتشخيصات، والتعويض، والرسم بإعدادات مناسبة لمسار إعداد الأشكال العلمية.

> [!NOTE]
> في هذا الإصدار المحلي، يشير `scripts/prepare_figure04.sh` إلى `publication_code/figure02_scan_segmentation.py`، لكن مجلد `publication_code/` غير موجود. احتفظ بهذا المسار إذا كان فرعك المحلي يحتوي هذا المجلد؛ وإلا فالأفضل استخدام `scripts/run_scan_pipeline.sh`.

## Internationalization

يستخدم المستودع سطرًا واحدًا فقط لخيارات اللغة أعلى كل README لتجنّب تكرار شريط اللغات.

الملفات المترجمة المتاحة حاليًا داخل `i18n/`:

- `README.ar.md`
- `README.de.md`
- `README.es.md`
- `README.fr.md`
- `README.ja.md`
- `README.ko.md`
- `README.ru.md`
- `README.vi.md`
- `README.zh-Hans.md`
- `README.zh-Hant.md`

### Language Coverage Matrix

| اللغة/المنطقة | الملف | التغطية |
|---|---|---|
| العربية | `README.ar.md` | ✅ موجود |
| الألمانية | `README.de.md` | ✅ موجود |
| الإسبانية | `README.es.md` | ✅ موجود |
| الفرنسية | `README.fr.md` | ✅ موجود |
| اليابانية | `README.ja.md` | ✅ موجود |
| الكورية | `README.ko.md` | ✅ موجود |
| الروسية | `README.ru.md` | ✅ موجود |
| الفيتنامية | `README.vi.md` | ✅ موجود |
| الصينية (المبسطة) | `README.zh-Hans.md` | ✅ موجود |
| الصينية (التقليدية) | `README.zh-Hant.md` | ✅ موجود |

| رابط اللغة في الشريط | الملف في `i18n/` | الحالة |
|---|---|---|
| العربية | `README.ar.md` | متوفر |
| Deutsch | `README.de.md` | متوفر |
| Español | `README.es.md` | متوفر |
| Français | `README.fr.md` | متوفر |
| 日本語 | `README.ja.md` | متوفر |
| 한국어 | `README.ko.md` | متوفر |
| Русский | `README.ru.md` | متوفر |
| Tiếng Việt | `README.vi.md` | متوفر |
| 中文 (简体) | `README.zh-Hans.md` | متوفر |
| 中文（繁體） | `README.zh-Hant.md` | متوفر |

يجب أن تحافظ جميع نسخ README على سطر واحد فقط لخيارات اللغة في الأعلى (من دون شريط لغات مكرر)، بما يتوافق مع `.auto-readme-work/*/language-nav-*.md`.

> [!NOTE]
> قاعدة صيانة التعدد اللغوي للتعديلات القادمة: بعد أي تعديل في أقسام الملف الجذر، حدّث كل ملف لغة واحدًا تلو الآخر، واحرص على عدم تكرار شريط اللغات في أي README محلي.

### Multilingual Update Checklist

1. حدّث ملف الجذر `README.md` أولًا.
2. تأكد من وجود `i18n/` وملفات اللغات المطلوبة.
3. حدّث كل ملف `i18n/README.<lang>.md` واحدًا تلو الآخر (من دون نسخ مجمّع لمحتوى قديم).
4. حافظ على سطر واحد فقط لخيارات اللغة في أعلى كل نسخة README.
5. تحقّق من عدم وجود أشرطة لغات مكررة في الجذر أو الملفات المحلية.

## Configuration

أهم خيارات CLI المستخدمة عبر السكربتات:

### Segmentation (`segment_robust_fixed.py`)

- `--time_bin_us`: حجم bin النشاط بالميكروثانية.
- `--round_trip_period`: فترة يدوية (الافتراضي `1688` bins).
- `--auto_calculate_period`: حساب الفترة عبر autocorrelation.
- `--activity_fraction`: نسبة نافذة الأحداث النشطة.
- `--manual_start_shift_ms`: إزاحة يدوية لبداية المسح.

### Compensation (`compensate_multiwindow_train_saved_params.py`)

- `--num_params` (الافتراضي `13`)، `--temperature` (الافتراضي `5000`).
- `--a_trainable` / `--a_fixed`, `--b_trainable` / `--b_fixed`, `--boundary_trainable`.
- `--a_default`, `--b_default`.
- `--iterations`, `--learning_rate`, `--smoothness_weight`.
- `--chunk_size` للتحكم بالذاكرة.
- `--load_params` لإعادة استخدام معاملات متعلّمة.

### Visualization

- `visualize_boundaries_and_frames.py`: `--sample_rate`, `--wavelength_min`, `--wavelength_max`, وخيارات حجم الحساس.
- `visualize_cumulative_compare.py`: حجم الحساس، `--output_dir`, `--sample_label`.
- `visualize_cumulative_weighted.py`: مقاييس القطبية، `--step_us`, `--auto_scale`, `--exp`, `--no_comp`.

## Examples

### Quick start dataset-style commands (from `QUICKSTART.md`)

```bash
python segment_robust_fixed.py \
  led_12v_no_acc_glass/glass/sync_recording_12v_led_no_acc_blank_event_20250804_232556.raw \
  --segment_events \
  --output_dir led_12v_no_acc_glass/glass/

python compensate_multiwindow_train_saved_params.py \
  led_12v_no_acc_glass/glass/sync_recording_12v_led_no_acc_blank_event_20250804_232556_segments/Scan_1_Forward_events.npz \
  --bin_width 50000 \
  --visualize --plot_params --a_trainable \
  --iterations 1000 \
  --b_default 0 \
  --smoothness_weight 0.001

python visualize_boundaries_and_frames.py \
  led_12v_no_acc_glass/glass/sync_recording_12v_led_no_acc_blank_event_20250804_232556_segments/Scan_1_Forward_events.npz
```

### Legacy helper commands retained from historical workflows

```bash
python scanning_alignment_visualization_save.py \
  led_12v_no_acc_glass/glass/sync_recording_12v_led_no_acc_blank_event_20250804_232556_segments/Scan_1_Forward_events.npz \
  --output_dir led_12v_no_acc_glass/glass/sync_recording_12v_led_no_acc_blank_event_20250804_232556_segments/FIXED_visualization

python scanning_alignment_visualization_cumulative_compare.py \
  led_12v_no_acc_glass/glass/sync_recording_12v_led_no_acc_blank_event_20250804_232556_segments/Scan_1_Forward_events.npz \
  --sensor_width 1280 --sensor_height 720 \
  --output_dir led_12v_no_acc_glass/glass/sync_recording_12v_led_no_acc_blank_event_20250804_232556_segments/cumulative_vs_bin2ms \
  --sample_label "led_12v_no_acc_glass Scan_1_Forward"
```

تم الإبقاء على هذه الأوامر القديمة عمدًا لتوفير سياق التوافق؛ في هذا الإصدار المحلي استخدم سكربتات الجذر الحالية كلما أمكن.

### Turbo multi-scan training

```bash
python compensate_multiwindow_turbo.py \
  --segments-dir path/to/your_segments \
  --include all --sort name \
  --bin-width 5000 \
  -- --a_trainable --iterations 1000 --smoothness_weight 0.001 --chunk_size 250000 --visualize --plot_params
```

### Reuse learned parameters (skip retraining)

```bash
python compensate_multiwindow_train_saved_params.py segment.npz \
  --load_params learned_params.npz
```

## Bill of Materials (Core Module)

راجع [`BOM/core_module.md`](../BOM/core_module.md) للاطلاع على الجدول الكامل مع الروابط والملاحظات.

### Table S2. Acquisition Time and Cost Comparison Between the Proposed Event-Driven System and a Reference Hyperspectral Camera

| Parameter | Ours | Reference camera |
|---|---|---|
| Acquisition time | ∼585 ms per scan | 300 s per scan |
| Data volume | 18.5 MB | 138 MB |
| Approx. price | ∼3000 USD | 14 000 USD |

### Table S3. Bill of Materials for the Core Scanning Illumination Module
(Excluding event camera and optional 4f validation optics)

| Component | Notes | Cost (USD) | Taobao Link |
|---|---|---:|---|
| Motion control | NEMA42 + TB6600 + Arduino Uno | 15.00 | https://e.tb.cn/h.7FHgkEvoo6tpKTo?tk=QYRFUPRqazE |
| Optics (grating) | Diffraction grating (education grade) | 3.47 | https://e.tb.cn/h.7Fhj16MkrSDHNnE?tk=3Q8dUPRouNw |
| Illumination | 2835 LED (6 CNY / 10 pcs; 0.6 CNY used) | 0.08 | https://e.tb.cn/h.7uubHIVL5diILHl?tk=tzTAUPRr14K |
| Reflector | Folding mirror | 6.25 | https://e.tb.cn/h.7uu1rNNSbgVdS31?tk=PqsxUPRHb32 |
| Electronics | LED PCB (CNY/board; min order 5 pcs) | 1.67 |  |
| Limit switches | Optional, 2 × 8.07 CNY | 2.24 | https://e.tb.cn/h.7FHEKbcgJmc2Ll1?tk=I4FRUP8diRE |
| 3D printing | One-third PLA filament spool (covers all printed parts) | 5.09 | https://e.tb.cn/h.7FhOVWX7SLHvNNf?tk=kOcQUPRJsbo |
| Lens | Plano-convex lens (25.4 mm, 350–700 nm AR) |  | https://e.tb.cn/h.7FSePNYhqt7ITbh?tk=tH8ZUP8i3cC |
| Total | core module | **33.99** |  |

## Core Scripts

### 1. Segmentation: `segment_robust_fixed.py`

**الهدف**: استخراج توقيت المسح من الأحداث الخام وتقطيعها إلى 6 مسحات أحادية الاتجاه (F, B, F, B, F, B).

**الوصف الرياضي**:

- **إشارة النشاط** (تجميع الأحداث ضمن bins بحجم $\Delta t = 1000~\mu\text{s}$):
  $$a[n] = \left|\{ i \mid t_{\min} + n\Delta t \le t_i < t_{\min} + (n+1)\Delta t \}\right|.$$

- **اكتشاف النافذة النشطة**: إيجاد أصغر نافذة متصلة تحتوي على $80\%$ من الأحداث.

- **تقدير الفترة**: autocorrelation أو فترة يدوية (الافتراضي: $1688$ bins).

- **الارتباط العكسي** (بنية التوقيت):
  $$R[k] = \sum_{n} a[n]\, a_{\text{rev}}[n+k]$$
  حيث
  $$a_{\text{rev}}[n] = a[N-1-n].$$

**الاستخدام**:

```bash
# Automatic period detection
python segment_robust_fixed.py recording.raw --segment_events --output_dir segments/

# Manual period (fixed 1688 bins)
python segment_robust_fixed.py recording.raw --segment_events --round_trip_period 1688
```

**المعاملات**:

- `--segment_events`: حفظ مقاطع المسح الفردية كملفات NPZ.
- `--round_trip_period 1688`: استخدام فترة يدوية (افتراضي).
- `--auto_calculate_period`: تجاوز الفترة اليدوية بحساب autocorrelation.
- `--activity_fraction 0.80`: نسبة الأحداث لمنطقة النشاط.
- `--max_iterations 2`: عدد تكرارات التحسين.

### 2. Compensation: `compensate_multiwindow_train_saved_params.py`

**الهدف**: تعلّم معاملات التشوّه الزمني لإزالة القص الزمني الناتج عن المسح عبر تعويض خطي-قطعي متعدد النوافذ.

**الوصف الرياضي**:

- **أسطح الحدود**:
  $$T_i(x, y) = a_i x + b_i y + c_i,\quad i=0,\ldots,M-1.$$

- **انتماءات نوافذ ناعمة**:
  $$m_i = \sigma\!\Big(\frac{t - T_i}{\tau}\Big)\,\sigma\!\Big(\frac{T_{i+1} - t}{\tau}\Big),\qquad w_i = \frac{m_i}{\sum_j m_j + \varepsilon}.$$

- **ميول مستوفاة (اختياري)**:
  $$\alpha_i = \frac{t - T_i}{T_{i+1} - T_i},\quad a_i' = (1-\alpha_i)a_i + \alpha_i a_{i+1},\quad b_i' = (1-\alpha_i)b_i + \alpha_i b_{i+1}.$$

- **التشوّه الزمني**:
  $$\Delta t(x,y,t) = \sum_i w_i (\tilde{a}_i x + \tilde{b}_i y),\qquad t' = t - \Delta t(x,y,t).$$

- **دالة الخسارة**: تقليل تباين الإطارات المجمعة زمنيًا مع تنظيم نعومة على المعاملات.

**الاستخدام**:

```bash
# Train with a-parameters trainable, b fixed
python compensate_multiwindow_train_saved_params.py segment.npz \
  --bin_width 50000 --a_trainable --b_default -76.0 \
  --iterations 1000 --smoothness_weight 0.001

# Load pre-trained parameters
python compensate_multiwindow_train_saved_params.py segment.npz \
  --load_params learned_params.npz
```

**أهم المعاملات**:

- `--a_trainable` / `--a_fixed`: التحكم في تدريب a (الافتراضي: ثابت).
- `--b_trainable` / `--b_fixed`: التحكم في تدريب b (الافتراضي: قابل للتدريب).
- `--num_params 13`: عدد معاملات الحدود.
- `--temperature 5000`: درجة حرارة sigmoid للنوافذ الناعمة.
- `--smoothness_weight 0.001`: وزن التنظيم.
- `--load_params file.npz`: تحميل معاملات محفوظة.
- `--chunk_size 250000`: حجم تجزئة لمعالجة موفرة للذاكرة.

### 3. Visualization: `visualize_boundaries_and_frames.py`

**الهدف**: عرض المعاملات المتعلّمة وإظهار التحسن النوعي.

**الميزات**:

- تراكب المعاملات على إسقاطات $x\text{–}t$ و $y\text{–}t$.
- مقارنة الإطارات المجمعة زمنيًا (أصلي مقابل مُعوَّض).
- تحليل نافذة منزلقة (50 ms و 2 ms bins).
- تعيين أطوال موجية للتصوّر الطيفي.

**الاستخدام**:

```bash
python visualize_boundaries_and_frames.py segment.npz \
  --sample_rate 0.1 --wavelength_min 380 --wavelength_max 680
```

### 4. Cumulative Comparison: `visualize_cumulative_compare.py`

**الهدف**: مقارنة المتوسطات التراكمية بخطوة 2 ms مع متوسطات النوافذ المنزلقة.

**الوصف الرياضي**:

- **المتوسطات التراكمية**:
  $$F(T) = \frac{1}{HW}\sum_{t < T}\text{events}(t).$$

- **المتوسطات المنزلقة**: عدد الأحداث في $[T-\Delta,\,T)$ مقسومًا على $H \times W$.

- **العلاقة** (مشتقة فروق منتهية):
  $$\Delta F(T) \approx \frac{F(T) - F(T-\Delta)}{\Delta}.$$

**الاستخدام**:

```bash
python visualize_cumulative_compare.py segment.npz \
  --sensor_width 1280 --sensor_height 720 \
  --sample_label "My Dataset"
```

## Additional Tools

### GUI Application: `scan_compensation_gui_cloud.py`

واجهة GUI كاملة لتعويض المسح مع تصوّر طيفي ثلاثي الأبعاد.

**الميزات**:

- ضبط تفاعلي للمعاملات.
- متابعة تقدم التحسين في الزمن الحقيقي.
- تصوّر ثلاثي الأبعاد مع تعيين الأطوال الموجية.
- تصدير النتائج والمعاملات.

**الاستخدام**:

```bash
python scan_compensation_gui_cloud.py
```

### Dual Camera System (current path)

نظام تسجيل متزامن لكاميرا الأحداث وكاميرا الإطارات:

- `ImagingGUI/DualCamera_separate_transform.py`

**الميزات**:

- تسجيل متزامن للأحداث والإطارات.
- معاينة فورية مع التحويلات.
- عناصر تحكم نافذة always-on-top.
- ضبط المعاملات أثناء التسجيل.

### Hyperspectral ENVI utilities

سكربتات داخل المستودع لعرض ENVI cube، واستخراج ROI، وتجهيزات التصوّر:

- `show_envi_spectrum_gui.py`
- `scripts/hs_to_rgb.py`
- `scripts/envi_export_frames.py`
- `scripts/envi_crop_by_roi.py`
- `scripts/hs_gradient_wavelength.py`
- `scripts/cellpose_roi.py`
- `scripts/cellpose_simple_mask.py`
- `scripts/roi_template_match.py`

نقطة تشغيل نموذجية:

```bash
python show_envi_spectrum_gui.py
```

### Arduino Motor Control (legacy path reference retained)

كان README الأصلي يشير إلى مسار firmware التالي:

- `rotor/step42_with_key_int/step42_with_key_int.ino`

التخطيط الحالي للمستودع يتضمن ملاحظات firmware هنا:

- `firmware/README.md`

هذا الاختلاف في المسارات محفوظ عمدًا؛ إذا كانت مجلدات rotor sketch لديك في فرع/نسخة محلية أخرى، فاستمر باستخدام تلك المسارات.

قدرات sketch الموثقة تاريخيًا (والمحفوظة هنا للتوافق):

- تحكم دقيق بالزاوية مع microstepping.
- ملفات تسارع/تباطؤ.
- تكامل limit switch.
- وظيفة تمركز تلقائي.

## Turbo Multi-Scan Compensation

عند توفر عدة مسحات أحادية الاتجاه (Forward/Backward) للمسح نفسه، يمكنك دمجها وتشغيل المدرب المُثبت على تيار أحداث مدمج واحد باستخدام `compensate_multiwindow_turbo.py`.

### What it does

- يقبل segment واحدًا، أو قائمة صريحة، أو مجلد segments كامل.
- في المسحات Backward، يقلب القطبية ويعكس الزمن قبل الدمج:
- إذا كانت القطبية `p ∈ {0,1}`: تصبح `p := 1 − p`، ثم يُعكس الزمن داخل المسح.
- إذا كانت القطبية `p ∈ {−1,1}`: تصبح `p := −p`، ثم يُعكس الزمن داخل المسح.
- يضمّ المسحات على خط زمني مستمر (بفاصل `1 μs` بين المسحات) ويستدعي `compensate_multiwindow_train_saved_params.py` داخليًا.

### Usage

```bash
# Merge all scans (Forward+Backward) from a segments folder and train at 5 ms
python compensate_multiwindow_turbo.py \
  --segments-dir path/to/.../_segments \
  --include all --sort name \
  --bin-width 5000 \
  -- --a_trainable --iterations 1000 --smoothness_weight 0.001 --chunk_size 250000 --visualize --plot_params

# Reuse learned params and just render at 10 ms (fast, no training)
python compensate_multiwindow_turbo.py \
  --segments-dir path/to/.../_segments \
  --include all --sort time \
  --bin-width 10000 \
  --load-params path/to/learned_params.npz \
  -- --visualize --plot_params

# Only Forward scans
python compensate_multiwindow_turbo.py \
  --segments-dir path/to/.../_segments \
  --include forward --sort time \
  --bin-width 5000 \
  -- --a_trainable --iterations 1000 --smoothness_weight 0.001 --chunk_size 250000
```

### Options

- `--segment`, `--segments`, `--segments-dir`: اختيار مجموعة الإدخال.
- `--include {all|forward|backward}`: تصفية حسب اتجاه المسح.
- `--sort {name|time}`: ترتيب طبيعي بالأسماء أو وفق `start_time` داخل NPZ.
- `--bin-width <μs>`: يُمرَّر إلى المدرب الأساسي.
- `--load-params`: إعادة استخدام معاملات محفوظة (تخطي التدريب وإعادة توليد المخرجات سريعًا بعروض bin جديدة).
- `--extra ...` بعد `--`: أي خيارات إضافية تُمرَّر إلى المدرب الأساسي.

### Speed scaling tip

إذا كانت المسحة أسرع بمقدار `N×` من خط الأساس، فخفّض `--bin-width` بنفس النسبة (مثلًا: خط أساس `50 ms` -> أسرع `10×` -> `5 ms`: استخدم `--bin-width 5000`). يمكنك التدريب مرة واحدة (مثلًا عند `5 ms`)، ثم استخدام `--load-params` لإعادة توليد النتائج بسرعة عند `10 ms` دون إعادة تدريب.

## Parameter Management

يدعم النظام آلية شاملة لحفظ/تحميل المعاملات.

### Save Formats

- **NPZ**: صيغة ثنائية للتحميل السريع.
- **JSON**: صيغة مقروءة مع metadata.
- **CSV**: متوافقة مع Excel للفحص اليدوي.

### Parameter Loading

```bash
# Load any supported format
python compensate_multiwindow_train_saved_params.py segment.npz \
  --load_params learned_params.npz
# or --load_params learned_params.json
# or --load_params learned_params.csv
```

### Parameter Files

تُسمى الملفات تلقائيًا وفق عدد المعاملات، مثل: `*_learned_params_n13.*`.

## Memory Optimization

يستخدم النظام معالجة مجزأة في جميع المراحل:

| العنصر | التفاصيل |
|---|---|
| Chunk Size | الافتراضي `250000` حدث (قابل للضبط) |
| Memory Efficient | معالجة مجموعات بيانات كبيرة دون تجاوز ذاكرة GPU |
| Unified Variance | الحفاظ على تدفق gradients صحيح أثناء التعلم |
| Progress Tracking | تحديثات معالجة في الزمن الحقيقي |

## Output Structure

```text
project/
├── data/
│   ├── recording.raw                    # Original RAW file
│   ├── recording_segments/              # Segmented scans
│   │   ├── Scan_1_Forward_events.npz
│   │   ├── Scan_2_Backward_events.npz
│   │   └── ...
│   ├── learned_params_n13.npz          # Trained parameters
│   ├── learned_params_n13.json
│   ├── learned_params_n13.csv
│   └── visualization_20240115_143022/  # Results
│       ├── events_with_params.png
│       ├── sliding_frames_*.npz
│       ├── frame_means_wavelength.png
│       └── time_binned_frames/         # Individual frames
```

### Typical Generated Artifacts

| نمط الملف | يُنتج بواسطة | الأهمية |
|---|---|---|
| `*_segments/Scan_*_events.npz` | التقسيم | مدخلات تدريب/تصوّر معيارية لكل مسح |
| `*learned_params_n13.npz` (وكذلك `.json`, `.csv`) | مدرب التعويض | إعادة الاستخدام، قابلية إعادة الإنتاج، والفحص |
| `visualization_YYYYmmdd_HHMMSS/` | سكربتات التصوّر / وضع التصوّر في المدرب | عزل مخرجات كل تشغيل بالطابع الزمني |
| `events_with_params.png` ومخططات الإطارات/التراكمي | سكربتات التصوّر | تحقق نوعي من تأثيرات التعويض |

## Configuration Examples

### High-Precision Compensation

```bash
python compensate_multiwindow_train_saved_params.py segment.npz \
  --num_params 21 --temperature 3000 --iterations 2000 \
  --a_trainable --b_trainable --boundary_trainable \
  --smoothness_weight 0.0001 --chunk_size 100000
```

### Fast Processing

```bash
python compensate_multiwindow_train_saved_params.py segment.npz \
  --num_params 7 --iterations 500 --chunk_size 500000 \
  --a_fixed --b_default -76.0
```

### Memory Constrained

```bash
python compensate_multiwindow_train_saved_params.py segment.npz \
  --chunk_size 50000 --bin_width 100000
```

## Wavelength Mapping

يدعم النظام التصوّر الطيفي عبر ربط التطور الزمني بالطول الموجي:

```python
# Linear mapping: time -> wavelength
wavelength = wavelength_min + (t_normalized / t_max) * (wavelength_max - wavelength_min)
```

**المدى الافتراضي**: $380\text{–}680~\text{nm}$ (قابل للضبط).

## Tips and Best Practices

### Parameter Selection

- **Microstepping**: استخدم `32×` لحركة سلسة (Arduino).
- **Bin Width**: ابدأ بـ `50 ms` للتحسين، و`2 ms` للتحليل.
- **Temperature**: القيم الأعلى (حوالي `5000`) لحدود أكثر نعومة.
- **Smoothness**: القيمة `0.001` تمنح تنظيمًا جيدًا.

### Memory Management

- **GPU Memory**: استخدم المعالجة المجزأة بحجم chunk مناسب.
- **Event Count**: يوصى بـ `> 10^6` حدث للتعلم المستقر.
- **Iterations**: غالبًا ما تكون `1000` تكرار كافية.

### File Organization

- أبقِ ملفات RAW وsegments في الدليل نفسه.
- تُكتشف ملفات المعاملات تلقائيًا وفق نمط التسمية.
- استخدم بادئات أسماء واضحة لتنظيم المخرجات.

## Development Notes

- يصف `versions.md` المراحل التاريخية للمشروع وأسباب الانتقال بينها.
- يمنع `.githooks/pre-commit` عمليات commit كبيرة/ثنائية وأنواع ملفات غير كود/توثيق.
- يضبط `scripts/setup_hooks.sh` قيمة `core.hooksPath` إلى `.githooks`.
- يحتوي `versions/05_archive_code_variants/` على نسخ سكربتات أقدم للحفاظ على تركيز أدوات الجذر الحالية.

### Developer Workflow Notes

- فضّل `scripts/run_scan_pipeline.sh` لتشغيلات baseline القابلة لإعادة الإنتاج، ثم انتقل لضبط السكربتات بشكل منفصل.
- اعتبر المسارات تحت `comparisons/` مثل `outputs_root/`, `reference_*`, و`align_*` مساحات مختلطة للتحليل/التاريخ؛ لا تفترض أنها عينات اختبار دنيا فقط.
- عند إضافة سكربتات جديدة، احرص أن تبقى نقاط الدخول في الجذر واضحة من هذا README مع ربط المستندات ذات الصلة (`QUICKSTART.md` وREADME الخاصة بالمجلدات الفرعية).

انحرافات توثيق معروفة (محفوظة عمدًا للتوافق الخلفي):

- تشير بعض الوثائق القديمة إلى `sync_image_system/` أو `dual_camera_gui.py`؛ بينما هذا الإصدار يحتوي `ImagingGUI/DualCamera_separate_transform.py` وأدلة SDK.
- لا يزال `ImagingGUI/README.md` يشير إلى `pip install -r requirements.txt`، لكن لا يوجد `requirements.txt` في الجذر بهذا الإصدار.
- يشير `firmware/README.md` إلى مجلدات Arduino sketch فرعية غير موجودة في هذا الإصدار.
- يذكر `versions.md` أسماء سكربتات قديمة تختلف عن أسماء السكربتات الحالية في الجذر.
- يتضمن `i18n/` حاليًا كل الملفات المرتبطة في شريط اللغات (`ar`, `de`, `es`, `fr`, `ja`, `ko`, `ru`, `vi`, `zh-Hans`, `zh-Hant`)؛ حافظ على تزامن ملفات الجذر والترجمة عند تعديل العناوين/الأقسام.

## Troubleshooting

| العَرَض | السبب المحتمل | الإجراء |
|---|---|---|
| أخطاء تحميل المعاملات | عدم تطابق عدد المعاملات | تأكد أن `--num_params` يطابق الملف المحفوظ |
| OOM / ضغط ذاكرة | chunk كبير جدًا أو bins دقيقة جدًا | قلّل `--chunk_size` و/أو زد `--bin_width` |
| جودة تعويض ضعيفة | تدريب غير كافٍ أو تقسيم ضعيف | زد `--iterations`، فعّل معاملات قابلة للتدريب، وتحقق من جودة التقسيم |
| عدم إنتاج ملفات segment | مشكلة في RAW/SDK/flags | تحقق من مسار RAW وإعداد Metavision ووجود `--segment_events` |
| تجاهل معاملات turbo wrapper | صياغة تمرير خاطئة | مرّر معاملات المدرب بعد `--` (أو استخدم `--extra`) |
| مشاكل GUI | عدم توافق Tkinter/backend أو SDK | تحقق من backend للواجهة وتوفر SDK الكاميرا |

قائمة فحص موسعة للأعطال (محفوظة للفحص السريع):

- **أخطاء تحميل المعاملات**: تأكد من توافق `--num_params` مع ملف المعاملات المحمّل.
- **OOM / ضغط ذاكرة**: قلّل `--chunk_size` و/أو زد `--bin_width`.
- **جودة تعويض ضعيفة**: زد `--iterations`، فعّل المعاملات القابلة للتدريب (`--a_trainable`, `--b_trainable`, واختياريًا `--boundary_trainable`)، وتحقق من جودة التقسيم.
- **لا توجد ملفات segment ناتجة**: تحقق من مسار RAW، وتوفر قارئ Metavision، وتمرير `--segment_events`.
- **تمرير معاملات Turbo wrapper**: ضع معاملات المدرب بعد `--` (أو استخدم `--extra`).
- **مشاكل GUI**: تحقق من دعم Tkinter backend وتوفر SDK الكاميرا على منصتك.

## Roadmap

- تحسين قابلية إعادة إنتاج بيئة التشغيل (`requirements.txt` أو lockfile للبيئة).
- توحيد أسماء السكربتات القديمة وإشارات المسارات عبر التوثيق.
- توسيع توثيق مخططات البيانات المتوقعة وحقول NPZ.
- إضافة اختبارات نمط regression للتقسيم/التعويض على بيانات fixture صغيرة.
- مواصلة دمج مخرجات تحليل بجودة نشر علمي من مسارات `align_*`.
- الحفاظ على تزامن README الجذر وجميع ملفات `i18n/README.*.md` مع تطور الأقسام.

## Citation

إذا كان هذا المستودع مفيدًا لأبحاثك، يُرجى الاستشهاد بمقالة Optica:

```bibtex
@article{chen2026self,
  title   = {Self-calibrated neuromorphic hyperspectral derivative imaging},
  author  = {Chen, Rongzhou and Wang, Chutian and Li, Yuxing and Cao, Yuqing and Zhu, Shuo and Lam, Edmund},
  journal = {Optica},
  volume  = {13},
  number  = {4},
  pages   = {587--590},
  year    = {2026},
  publisher = {Optica Publishing Group},
  doi     = {10.1364/OPTICA.585766}
}
```

## Acknowledgements

- مقالة Optica المنشورة والمواد المرتبطة بنشر المشروع.
- مساهمو العتاد والبرمجيات عبر تطور المستودع كما هو موثق في `versions/` والأدوات المؤرشفة.
- دعم المجتمع عبر GitHub Sponsors وقنوات المشروع المرتبطة.

## License

هذا المشروع مرخّص بموجب MIT License. راجع [`LICENSE`](../LICENSE) للتفاصيل.

## Contributing

المساهمات مرحب بها.

- ابدأ من نمط السكربتات والتوثيق الحالي.
- احرص على أن تكون أمثلة سطر الأوامر قابلة لإعادة التشغيل باستخدام مسارات المستودع قدر الإمكان.
- عند إضافة بيانات/مخرجات كبيرة، التزم بسياسات `.githooks/pre-commit`.

ملاحظة: لا يوجد `CONTRIBUTING.md` مخصص في هذا الإصدار المحلي. عند الحاجة، افتح issue أو أرسل PR يتضمن آلية المساهمة التي تقترحها.

## Support / Sponsor

| القناة | الرابط | الاستخدام |
|---|---|---|
| GitHub Sponsors | https://github.com/sponsors/lachlanchen | دعم المشروع واستدامته |
| موقع المشروع | https://lazying.art | تحديثات المشروع وروابط المنظومة |
| دردشة المجتمع | https://chat.lazying.art | نقاشات المجتمع |
| صفحة منشئ إضافية | https://onlyideas.art | محتوى منشئ/بحثي ذي صلة |
| صفحة شراء الحزمة الأساسية | https://lazying.art/openhi-kit.html | حزمة عتاد البداية لمسار OpenHI |
| رمز ترويجي | `OPTICA` | خصم 30% (كما ورد أعلاه) |

### Support Scope

| نوع الدعم | أفضل قناة |
|---|---|
| التمويل والاستدامة | GitHub Sponsors |
| منظومة البناء/الشراء | صفحة OpenHI kit على `lazying.art` |
| استكشاف أخطاء المجتمع | `chat.lazying.art` |
| تحديثات المشروع العامة | `lazying.art` وصفحات المنشئ |

---

### Notes

- 📌 يحافظ هذا README على ملاحظات المسارات القديمة حيث أدّى تطور المستودع إلى اختلافات في الأسماء/البنية.
- 🔒 عند عدم اليقين في المراجع القديمة، يتم الإبقاء على النص عمدًا بدل حذفه.

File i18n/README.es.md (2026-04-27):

[English](../README.md) · [العربية](README.ar.md) · [Español](README.es.md) · [Français](README.fr.md) · [日本語](README.ja.md) · [한국어](README.ko.md) · [Tiếng Việt](README.vi.md) · [中文 (简体)](README.zh-Hans.md) · [中文（繁體）](README.zh-Hant.md) · [Deutsch](README.de.md) · [Русский](README.ru.md)

# Imagen Hiperespectral Neuromórfica Auto-Calibrada (OpenHI)














> [!NOTE]
> Estado de i18n en este checkout: todos los archivos de traducción enlazados están presentes en `i18n/` (`ar`, `de`, `es`, `fr`, `ja`, `ko`, `ru`, `vi`, `zh-Hans`, `zh-Hant`), con el README en inglés como referencia canónica raíz.

Un pipeline integral para reconstruir espectros a partir de cámaras de eventos con iluminación dispersa (por ejemplo, rejilla de difracción). El sistema registra eventos de cambio de intensidad $e = (x, y, t, p)$ donde $p \in \{-1, +1\}$ indica la polaridad del cambio de log-intensidad, e infiere automáticamente el tiempo de escaneo y metadatos de calibración ("auto info") directamente desde el flujo de eventos.

> [!IMPORTANT]
> Este README es la fuente técnica canónica en la raíz del repositorio. Los archivos localizados en `i18n/` deben reflejar la evolución de secciones/encabezados y mantener exactamente una línea de opciones de idioma al inicio (sin barras de idioma duplicadas).

<p align="center">
  Configuración del dispositivo
  GUI de adquisición
</p>

*Izquierda: microscopio de transmisión modular con brazo motorizado de iluminación por rejilla y pila de detección vertical. Derecha: GUI de adquisición de datos usada para monitorizar segmentación, compensación y reconstrucciones en tiempo real.*

## Acceso Rápido

| Necesidad | Ir a |
|---|---|
| Empezar en ~5 minutos | [Inicio Rápido (Ruta de 5 Minutos) ⚡](#inicio-rápido-ruta-de-5-minutos) |
| Ejecutar el wrapper del pipeline completo | [`scripts/run_scan_pipeline.sh`](../scripts/run_scan_pipeline.sh) |
| Entender el flujo de scripts | [Resumen General 🔭](#resumen-general), [Scripts Principales 🧠](#scripts-principales) |
| Ajustar parámetros | [Configuración 🎛️](#configuración), [Ejemplos de Configuración 🧩](#ejemplos-de-configuración) |
| Usar herramientas GUI | [Herramientas Adicionales 🛠️](#herramientas-adicionales) |
| Documentación de hardware (BOM/PCB/3D/Firmware) | [Mapa del Repositorio 🗺️](#mapa-del-repositorio) |
| Reglas de mantenimiento multilingüe | [Internacionalización 🌍](#internacionalización) |
| Enlaces de soporte/patrocinio | [Soporte / Patrocinio 💖](#soporte--patrocinio) |

## De un Vistazo

| Elemento | Detalles |
|---|---|
| Idea central | Imagen derivativa hiperespectral auto-calibrada desde flujos de eventos |
| Etapas principales | `segment_robust_fixed.py` -> `compensate_multiwindow_train_saved_params.py` -> scripts de visualización |
| Documentación de hardware en el repo | `3D/`, `PCB/`, `firmware/`, `BOM/` |
| Herramientas de escritorio | `scan_compensation_gui_cloud.py`, `ImagingGUI/DualCamera_separate_transform.py` |
| Artículo canónico | [Artículo de Optica (DOI: 10.1364/OPTICA.585766)](https://doi.org/10.1364/OPTICA.585766) |
| i18n en este checkout | `README.ar.md`, `README.de.md`, `README.es.md`, `README.fr.md`, `README.ja.md`, `README.ko.md`, `README.ru.md`, `README.vi.md`, `README.zh-Hans.md`, `README.zh-Hant.md` |

### Resumen de Compatibilidad

| Área | Situación actual del repositorio |
|---|---|
| Base de Python | Se recomienda `3.9+` (algunas utilidades de `ImagingGUI/` indican `3.10+`) |
| Lanzador principal del pipeline | `scripts/run_scan_pipeline.sh` |
| Script principal de entrenamiento | `compensate_multiwindow_train_saved_params.py` |
| Material de hardware | Disponible en `3D/`, `PCB/`, `BOM/`, `firmware/` |
| Documentación multilingüe | `i18n/` contiene los 10 archivos de idioma enlazados |

> [!TIP]
> Compra el kit de desarrollo central (sin incluir cámara, lente tubular ni mesa óptica) para el artículo [Self-calibrated neuromorphic hyperspectral derivative imaging](https://doi.org/10.1364/OPTICA.585766) publicado en Optica:
> - https://lazying.art/openhi-kit.html
> - Código promocional con 30% de descuento: `OPTICA`

## Contenidos

- [Acceso Rápido ⚡](#acceso-rápido)
- [De un Vistazo 📌](#de-un-vistazo)
- [Resumen General 🔭](#resumen-general)
- [Características ✨](#características)
- [Mapa del Repositorio 🗺️](#mapa-del-repositorio)
- [Estructura del Proyecto 📁](#estructura-del-proyecto)
- [Inicio Rápido (Ruta de 5 Minutos) ⚡](#inicio-rápido-ruta-de-5-minutos)
- [Prerrequisitos 🧰](#prerrequisitos)
- [Instalación ⚙️](#instalación)
- [Uso 🚀](#uso)
- [Internacionalización 🌍](#internacionalización)
- [Configuración 🎛️](#configuración)
- [Ejemplos 🧪](#ejemplos)
- [Lista de Materiales (Módulo Central) 🧾](#lista-de-materiales-módulo-central)
- [Scripts Principales 🧠](#scripts-principales)
- [Herramientas Adicionales 🛠️](#herramientas-adicionales)
- [Compensación Turbo Multi-Scan ⚡](#compensación-turbo-multi-scan)
- [Gestión de Parámetros 💾](#gestión-de-parámetros)
- [Optimización de Memoria 🧱](#optimización-de-memoria)
- [Estructura de Salida 📦](#estructura-de-salida)
- [Ejemplos de Configuración 🧩](#ejemplos-de-configuración)
- [Mapeo de Longitud de Onda 🌈](#mapeo-de-longitud-de-onda)
- [Consejos y Buenas Prácticas ✅](#consejos-y-buenas-prácticas)
- [Notas de Desarrollo 🧭](#notas-de-desarrollo)
- [Solución de Problemas 🩺](#solución-de-problemas)
- [Hoja de Ruta 🛣️](#hoja-de-ruta)
- [Cita 📎](#cita)
- [Agradecimientos 🙏](#agradecimientos)
- [Licencia 📄](#licencia)
- [Contribuciones 🤝](#contribuciones)
- [Soporte / Patrocinio 💖](#soporte--patrocinio)

> [!IMPORTANT]
> Política de fuente de contenido canónico para este repositorio: mantener el `README.md` raíz en inglés como referencia técnica y reflejar la evolución de secciones/encabezados en cada variante `i18n/README.*.md` con una única línea de opciones de idioma al inicio.

## Resumen General

Cuando la iluminación barre longitudes de onda a lo largo del tiempo, el flujo de eventos codifica una derivada temporal del espectro subyacente a lo largo del eje de dispersión.

```text
RAW event recording
   -> scan timing segmentation (F/B passes)
   -> multi-window time-warp compensation
   -> frame/cumulative/wavelength diagnostics
```

### Leyenda del Pipeline

| Icono | Significado |
|---|---|
| 🧩 | Segmentación / división de escaneos |
| 🧠 | Compensación / aprendizaje de parámetros |
| 🖼️ | Diagnósticos visuales / inspección de salidas |
| 🌈 | Mapeo de longitud de onda / renderizado espectral |

Este pipeline proporciona tres etapas principales:

| Etapa | Objetivo | Script(s) principal(es) |
|---|---|---|
| 1. Segmentar | Encontrar el tiempo de escaneo y dividir grabaciones en pasadas hacia delante/hacia atrás | `segment_robust_fixed.py` |
| 2. Compensar | Estimar un time-warp lineal por tramos para eliminar la inclinación temporal inducida por el escaneo | `compensate_multiwindow_train_saved_params.py` |
| 3. Visualizar | Superponer límites aprendidos y comparar frames con bins temporales originales vs. compensados | `visualize_boundaries_and_frames.py`, `visualize_cumulative_compare.py` |

El repositorio también incluye recursos de hardware, código de GUI de adquisición y ramas de experimentos archivados en `versions/`.

### Alcance y Suposiciones

- Este repositorio está orientado a investigación e incluye scripts activos más experimentos/resultados archivados.
- Los comandos de este README asumen ejecución desde la raíz del repositorio, salvo que se indique lo contrario.
- Varios flujos opcionales dependen de SDKs externos (Metavision, SDKs de fabricantes de cámaras) y de datasets locales que no se incluyen en este repositorio.
- Si un comando hace referencia a una ruta histórica ausente, prioriza los scripts raíz actualizados listados en este README y conserva las notas heredadas solo para compatibilidad retroactiva.

## Características

- Flujo de trabajo integral de procesamiento de eventos desde RAW hasta espectro.
- Detección automática/manual de periodo de escaneo y segmentación hacia delante/hacia atrás.
- Compensación multi-ventana con modos de parámetros entrenables/fijos.
- Guardado/carga de parámetros en `NPZ`, `JSON` y `CSV`.
- Flujo de combinación multi-scan para iteraciones de entrenamiento más rápidas (`compensate_multiwindow_turbo.py`).
- Suite de visualización para límites, frames con bins, curvas acumulativas y diagnósticos ponderados.
- Documentación de hardware: BOM, PCB, piezas 3D, notas de firmware.
- Utilidades de adquisición para configuraciones sincronizadas de cámaras de eventos/frame.

| Categoría | Capacidades incluidas |
|---|---|
| Procesamiento de señal | Segmentación, detección de periodo, compensación por time-warp |
| Optimización | Parámetros entrenables/fijos, controles de suavidad, entrenamiento por bloques |
| Salidas | Superposiciones visuales, comparativas acumulativas, diagnósticos mapeados por longitud de onda |
| Activos de plataforma | Archivos de diseño de hardware, notas de firmware, herramientas GUI, archivos históricos |

## Mapa del Repositorio

Los recursos clave de hardware se mantienen junto al código para acceso rápido:

| Área | Ruta |
|---|---|
| Piezas impresas en 3D | [`3D/`](../3D/) |
| Diseños de PCB | [`PCB/`](../PCB/) |
| Firmware de microcontrolador | [`firmware/`](../firmware/) |
| Interfaz de adquisición (escritorio) | [`ImagingGUI/`](../ImagingGUI/) |
| Referencias de experimento/datos | [`comparisons/reference_spectrum_2835/`](../comparisons/reference_spectrum_2835/), [`comparisons/reference_spectrum_lumileds/`](../comparisons/reference_spectrum_lumileds/), [`references/`](../references/) |
| Análisis de alineación | [`comparisons/align_background_vs_reference_code/`](../comparisons/align_background_vs_reference_code/), [`comparisons/alignment_configs/`](../comparisons/alignment_configs/) |

## Estructura del Proyecto

```text
OpenHI/
├── README.md
├── QUICKSTART.md
├── LICENSE
├── versions.md
├── 3D/
├── BOM/
├── PCB/
├── firmware/
├── ImagingGUI/
├── scripts/
├── segment_robust_fixed.py
├── compensate_multiwindow_train_saved_params.py
├── compensate_multiwindow_turbo.py
├── compensate_multiwindow*.py
├── visualize_boundaries_and_frames.py
├── visualize_cumulative_compare.py
├── visualize_cumulative_weighted.py
├── scan_compensation_gui_cloud.py
├── show_envi_spectrum_gui.py
├── simple_raw_reader.py
├── comparisons/align_background_vs_reference_code/
├── align_data_vs_filter_code/
├── comparisons/alignment_configs/
├── versions/05_archive_code_variants/
├── comparisons/outputs_root/
├── comparisons/reference_filters/
├── comparisons/reference_spectrum_2835/
├── comparisons/reference_spectrum_lumileds/
├── references/
├── i18n/
└── versions/
```

## Inicio Rápido (Ruta de 5 Minutos)

Si tu entorno ya está preparado y la carpeta del dataset contiene un archivo `*event*.raw`:

```bash
scripts/run_scan_pipeline.sh /path/to/dataset_dir
```

Para forzar un archivo RAW específico:

```bash
scripts/run_scan_pipeline.sh /path/to/dataset_dir /path/to/recording_event.raw
```

Este wrapper ejecuta segmentación, entrenamiento de compensación y visualización usando rutas de scripts y flags CLI por defecto del repositorio.

> [!TIP]
> Para una primera validación, ejecuta el wrapper sobre un directorio de dataset, y luego inspecciona el NPZ segmentado generado y las salidas de visualización antes de ajustar las variables `PIPELINE_*`.

## Prerrequisitos

- Python 3.9+ (Python 3.10+ para algunas herramientas GUI en `ImagingGUI/`).
- Paquetes Python principales: `numpy`, `torch`, `matplotlib`.
- Opcionales pero comunes: `opencv-python`, `pillow`, `cellpose`, `spectral`.
- Paquete opcional específico de plataforma: `pywin32` (normalmente para flujos de trabajo de SDK de cámara en Windows).
- SDK de Metavision / bindings Python para flujos de lectura RAW de eventos (`simple_raw_reader.py`, segmentación desde RAW).
- Se recomienda PyTorch con CUDA para optimización más rápida.
- Grabaciones RAW y/o archivos NPZ segmentados disponibles localmente.

## Instalación

Actualmente no se proporciona un archivo de entorno bloqueado en la raíz del repositorio. Configuración sugerida:

```bash
# create and activate a virtual environment or conda env
python -m venv .venv
source .venv/bin/activate

# install core dependencies
pip install numpy matplotlib torch

# optional tools often used in this repository
pip install opencv-python pillow
# pip install cellpose
# pip install spectral pywin32
```

Si usas Git hooks para higiene de archivos grandes:

```bash
bash scripts/setup_hooks.sh
```

Recomendado (opcional) para verificaciones de reproducibilidad:

```bash
python -c "import numpy, torch, matplotlib; print('core deps ok')"
python -c "import torch; print('cuda:', torch.cuda.is_available())"
```

## Uso

### Flujo de Trabajo Básico (scripts raíz actuales)

```bash
# 1. Segment RAW into 6 scans (Forward/Backward)
python segment_robust_fixed.py \
  data/recording.raw \
  --segment_events \
  --output_dir data/segments/

# 2. Train multi-window compensation
python compensate_multiwindow_train_saved_params.py \
  data/segments/Scan_1_Forward_events.npz \
  --bin_width 50000 \
  --visualize --plot_params --a_trainable \
  --iterations 1000

# 3. Visualize results with boundaries
python visualize_boundaries_and_frames.py \
  data/segments/Scan_1_Forward_events.npz

# 4. Compare cumulative vs multi-bin means
python visualize_cumulative_compare.py \
  data/segments/Scan_1_Forward_events.npz \
  --sensor_width 1280 --sensor_height 720
```

### Referencia Comando-a-Salida

| Paso | Punto de entrada del comando | Salida principal |
|---|---|---|
| 🧩 Segmentar escaneos | `segment_robust_fixed.py` | `*_segments/Scan_*_{Forward,Backward}_events.npz` |
| 🧠 Entrenar compensación | `compensate_multiwindow_train_saved_params.py` | `*learned_params_n*.{npz,json,csv}` + diagnósticos visuales |
| 🖼️ Diagnóstico de límites/frames | `visualize_boundaries_and_frames.py` | carpeta de visualización con marca de tiempo, overlays y bins |
| 📈 Diagnóstico acumulativo | `visualize_cumulative_compare.py`, `visualize_cumulative_weighted.py` | gráficas acumulativas/estadísticas para control de calidad del escaneo |
| ⚡ Ejecución completa conveniente | `scripts/run_scan_pipeline.sh` | segmentación + entrenamiento + visualización de extremo a extremo |

### Wrapper de conveniencia de un solo comando

```bash
scripts/run_scan_pipeline.sh /path/to/dataset_dir [raw_file]
```

### Prueba Rápida Mínima (sin cambios de entrenamiento)

Úsala cuando quieras validar el cableado de scripts sobre un NPZ segmentado existente antes de ejecutar optimizaciones largas:

```bash
# quick visualization pass
python visualize_boundaries_and_frames.py /path/to/Scan_1_Forward_events.npz \
  --sample_rate 0.05 --sensor_width 1280 --sensor_height 720

# quick cumulative diagnostics
python visualize_cumulative_compare.py /path/to/Scan_1_Forward_events.npz \
  --sensor_width 1280 --sensor_height 720
```

Variables de entorno soportadas por `scripts/run_scan_pipeline.sh`:

| Variable | Valor por defecto | Objetivo |
|---|---:|---|
| `PIPELINE_ACTIVITY_FRACTION` | `0.90` | Fracción de ventana de eventos activos |
| `PIPELINE_BIN_WIDTH` | `50000` | Ancho de bin de entrenamiento en microsegundos |
| `PIPELINE_SENSOR_WIDTH` | `1280` | Ancho del sensor para visualización |
| `PIPELINE_SENSOR_HEIGHT` | `720` | Alto del sensor para visualización |
| `PIPELINE_SAMPLE_RATE` | `0.10` | Fracción de muestreo de eventos para gráficas |
| `PIPELINE_TIME_BIN_US` | `1000` | Tamaño del bin de actividad para segmentación |
| `PIPELINE_SEGMENT_PATTERN` | `Scan_1_Forward_events.npz` | Patrón de archivo segmentado para scripts posteriores |

### Wrapper orientado a figuras (flujo de publicación)

```bash
scripts/prepare_figure04.sh /path/to/dataset_dir [raw_file]
```

Este wrapper ejecuta segmentación, diagnósticos, compensación y graficado con valores por defecto orientados a figuras.

> [!NOTE]
> En este checkout, `scripts/prepare_figure04.sh` referencia `publication_code/figure02_scan_segmentation.py`, pero el directorio `publication_code/` no está presente. Conserva esta ruta si tu rama local incluye esa carpeta; en caso contrario prioriza `scripts/run_scan_pipeline.sh`.

## Internacionalización

El repositorio usa una única línea de opciones de idioma al inicio de cada README para evitar barras de idioma duplicadas.

Archivos traducidos actualmente disponibles en `i18n/`:

- `README.ar.md`
- `README.de.md`
- `README.es.md`
- `README.fr.md`
- `README.ja.md`
- `README.ko.md`
- `README.ru.md`
- `README.vi.md`
- `README.zh-Hans.md`
- `README.zh-Hant.md`

### Matriz de Cobertura de Idiomas

| Configuración regional | Archivo | Cobertura |
|---|---|---|
| Árabe | `README.ar.md` | ✅ Presente |
| Alemán | `README.de.md` | ✅ Presente |
| Español | `README.es.md` | ✅ Presente |
| Francés | `README.fr.md` | ✅ Presente |
| Japonés | `README.ja.md` | ✅ Presente |
| Coreano | `README.ko.md` | ✅ Presente |
| Ruso | `README.ru.md` | ✅ Presente |
| Vietnamita | `README.vi.md` | ✅ Presente |
| Chino (Simplificado) | `README.zh-Hans.md` | ✅ Presente |
| Chino (Tradicional) | `README.zh-Hant.md` | ✅ Presente |

| Enlace de idioma en navegación | Archivo en `i18n/` | Estado |
|---|---|---|
| العربية | `README.ar.md` | Disponible |
| Deutsch | `README.de.md` | Disponible |
| Español | `README.es.md` | Disponible |
| Français | `README.fr.md` | Disponible |
| 日本語 | `README.ja.md` | Disponible |
| 한국어 | `README.ko.md` | Disponible |
| Русский | `README.ru.md` | Disponible |
| Tiếng Việt | `README.vi.md` | Disponible |
| 中文 (简体) | `README.zh-Hans.md` | Disponible |
| 中文（繁體） | `README.zh-Hant.md` | Disponible |

Todas las variantes README deben mantener una única línea de opciones de idioma al inicio (sin barras de idioma duplicadas), consistente con `.auto-readme-work/*/language-nav-*.md`.

> [!NOTE]
> Regla de mantenimiento multilingüe para futuras ediciones: actualiza cada archivo de idioma uno por uno tras cambiar secciones raíz, y mantén barras de idioma no duplicadas en cada README localizado.

### Lista de Verificación de Actualización Multilingüe

1. Actualiza primero el `README.md` raíz.
2. Asegura que `i18n/` exista y que los archivos de idioma estén presentes.
3. Actualiza cada `i18n/README.<lang>.md` uno por uno (no copies en lote contenido obsoleto).
4. Mantén una sola línea de opciones de idioma al inicio de cada variante README.
5. Verifica que no haya barras de idioma duplicadas en archivos raíz o localizados.

## Configuración

Controles CLI importantes usados en los scripts:

### Segmentación (`segment_robust_fixed.py`)

- `--time_bin_us`: tamaño del bin de actividad en microsegundos.
- `--round_trip_period`: periodo manual (por defecto `1688` bins).
- `--auto_calculate_period`: periodo por autocorrelación.
- `--activity_fraction`: fracción de ventana de eventos activos.
- `--manual_start_shift_ms`: desplazamiento manual del inicio del escaneo.

### Compensación (`compensate_multiwindow_train_saved_params.py`)

- `--num_params` (por defecto `13`), `--temperature` (por defecto `5000`).
- `--a_trainable` / `--a_fixed`, `--b_trainable` / `--b_fixed`, `--boundary_trainable`.
- `--a_default`, `--b_default`.
- `--iterations`, `--learning_rate`, `--smoothness_weight`.
- `--chunk_size` para control de memoria.
- `--load_params` para reutilizar parámetros aprendidos.

### Visualización

- `visualize_boundaries_and_frames.py`: `--sample_rate`, `--wavelength_min`, `--wavelength_max`, argumentos de tamaño de sensor.
- `visualize_cumulative_compare.py`: tamaño de sensor, `--output_dir`, `--sample_label`.
- `visualize_cumulative_weighted.py`: escalas de polaridad, `--step_us`, `--auto_scale`, `--exp`, `--no_comp`.

## Ejemplos

### Comandos estilo dataset de inicio rápido (de `QUICKSTART.md`)

```bash
python segment_robust_fixed.py \
  led_12v_no_acc_glass/glass/sync_recording_12v_led_no_acc_blank_event_20250804_232556.raw \
  --segment_events \
  --output_dir led_12v_no_acc_glass/glass/

python compensate_multiwindow_train_saved_params.py \
  led_12v_no_acc_glass/glass/sync_recording_12v_led_no_acc_blank_event_20250804_232556_segments/Scan_1_Forward_events.npz \
  --bin_width 50000 \
  --visualize --plot_params --a_trainable \
  --iterations 1000 \
  --b_default 0 \
  --smoothness_weight 0.001

python visualize_boundaries_and_frames.py \
  led_12v_no_acc_glass/glass/sync_recording_12v_led_no_acc_blank_event_20250804_232556_segments/Scan_1_Forward_events.npz
```

### Comandos auxiliares heredados, conservados de flujos históricos

```bash
python scanning_alignment_visualization_save.py \
  led_12v_no_acc_glass/glass/sync_recording_12v_led_no_acc_blank_event_20250804_232556_segments/Scan_1_Forward_events.npz \
  --output_dir led_12v_no_acc_glass/glass/sync_recording_12v_led_no_acc_blank_event_20250804_232556_segments/FIXED_visualization

python scanning_alignment_visualization_cumulative_compare.py \
  led_12v_no_acc_glass/glass/sync_recording_12v_led_no_acc_blank_event_20250804_232556_segments/Scan_1_Forward_events.npz \
  --sensor_width 1280 --sensor_height 720 \
  --output_dir led_12v_no_acc_glass/glass/sync_recording_12v_led_no_acc_blank_event_20250804_232556_segments/cumulative_vs_bin2ms \
  --sample_label "led_12v_no_acc_glass Scan_1_Forward"
```

Estos comandos heredados se conservan intencionalmente por contexto de compatibilidad; en este checkout, usa los scripts raíz actuales siempre que sea posible.

### Entrenamiento turbo multi-scan

```bash
python compensate_multiwindow_turbo.py \
  --segments-dir path/to/your_segments \
  --include all --sort name \
  --bin-width 5000 \
  -- --a_trainable --iterations 1000 --smoothness_weight 0.001 --chunk_size 250000 --visualize --plot_params
```

### Reutilizar parámetros aprendidos (omitir reentrenamiento)

```bash
python compensate_multiwindow_train_saved_params.py segment.npz \
  --load_params learned_params.npz
```

## Lista de Materiales (Módulo Central)

Consulta [`BOM/core_module.md`](../BOM/core_module.md) para la tabla completa con enlaces y notas.

### Tabla S2. Comparación de Tiempo de Adquisición y Coste Entre el Sistema Propuesto Basado en Eventos y una Cámara Hiperespectral de Referencia

| Parámetro | Nuestro sistema | Cámara de referencia |
|---|---|---|
| Tiempo de adquisición | ∼585 ms por escaneo | 300 s por escaneo |
| Volumen de datos | 18.5 MB | 138 MB |
| Precio aproximado | ∼3000 USD | 14 000 USD |

### Tabla S3. Lista de Materiales para el Módulo Central de Iluminación de Escaneo
(Excluyendo la cámara de eventos y la óptica opcional 4f de validación)

| Componente | Notas | Coste (USD) | Enlace de Taobao |
|---|---|---:|---|
| Control de movimiento | NEMA42 + TB6600 + Arduino Uno | 15.00 | https://e.tb.cn/h.7FHgkEvoo6tpKTo?tk=QYRFUPRqazE |
| Óptica (rejilla) | Rejilla de difracción (grado educativo) | 3.47 | https://e.tb.cn/h.7Fhj16MkrSDHNnE?tk=3Q8dUPRouNw |
| Iluminación | LED 2835 (6 CNY / 10 uds; 0.6 CNY usado) | 0.08 | https://e.tb.cn/h.7uubHIVL5diILHl?tk=tzTAUPRr14K |
| Reflector | Espejo plegable | 6.25 | https://e.tb.cn/h.7uu1rNNSbgVdS31?tk=PqsxUPRHb32 |
| Electrónica | PCB LED (CNY/placa; pedido mínimo 5 uds) | 1.67 |  |
| Finales de carrera | Opcional, 2 × 8.07 CNY | 2.24 | https://e.tb.cn/h.7FHEKbcgJmc2Ll1?tk=I4FRUP8diRE |
| Impresión 3D | Un tercio de bobina PLA (cubre todas las piezas impresas) | 5.09 | https://e.tb.cn/h.7FhOVWX7SLHvNNf?tk=kOcQUPRJsbo |
| Lente | Lente plano-convexa (25.4 mm, AR 350–700 nm) |  | https://e.tb.cn/h.7FSePNYhqt7ITbh?tk=tH8ZUP8i3cC |
| Total | módulo central | **33.99** |  |

## Scripts Principales

### 1. Segmentación: `segment_robust_fixed.py`

**Objetivo**: Extraer el tiempo de escaneo de eventos RAW y dividir en 6 escaneos unidireccionales (F, B, F, B, F, B).

**Descripción Matemática**:

- **Señal de actividad** (eventos agrupados con $\Delta t = 1000~\mu\text{s}$):
  $$a[n] = \left|\{ i \mid t_{\min} + n\Delta t \le t_i < t_{\min} + (n+1)\Delta t \}\right|.$$

- **Detección de ventana activa**: encontrar la ventana contigua más pequeña que contiene el $80\%$ de los eventos.

- **Estimación de periodo**: autocorrelación o periodo manual (por defecto: $1688$ bins).

- **Correlación inversa** (estructura temporal):
  $$R[k] = \sum_{n} a[n]\, a_{\text{rev}}[n+k]$$
  con
  $$a_{\text{rev}}[n] = a[N-1-n].$$

**Uso**:

```bash
# Automatic period detection
python segment_robust_fixed.py recording.raw --segment_events --output_dir segments/

# Manual period (fixed 1688 bins)
python segment_robust_fixed.py recording.raw --segment_events --round_trip_period 1688
```

**Argumentos**:

- `--segment_events`: Guarda segmentos individuales de escaneo como archivos NPZ.
- `--round_trip_period 1688`: Usa periodo manual (por defecto).
- `--auto_calculate_period`: Sustituye el periodo manual por autocorrelación.
- `--activity_fraction 0.80`: Fracción de eventos para la región activa.
- `--max_iterations 2`: Iteraciones de refinamiento.

### 2. Compensación: `compensate_multiwindow_train_saved_params.py`

**Objetivo**: Aprender parámetros de time-warp para eliminar el cizallamiento temporal inducido por el escaneo usando compensación lineal por tramos multi-ventana.

**Descripción Matemática**:

- **Superficies de frontera**:
  $$T_i(x, y) = a_i x + b_i y + c_i,\quad i=0,\ldots,M-1.$$

- **Pertenencias suaves de ventana**:
  $$m_i = \sigma\!\Big(\frac{t - T_i}{\tau}\Big)\,\sigma\!\Big(\frac{T_{i+1} - t}{\tau}\Big),\qquad w_i = \frac{m_i}{\sum_j m_j + \varepsilon}.$$

- **Pendientes interpoladas (opcional)**:
  $$\alpha_i = \frac{t - T_i}{T_{i+1} - T_i},\quad a_i' = (1-\alpha_i)a_i + \alpha_i a_{i+1},\quad b_i' = (1-\alpha_i)b_i + \alpha_i b_{i+1}.$$

- **Time warp**:
  $$\Delta t(x,y,t) = \sum_i w_i (\tilde{a}_i x + \tilde{b}_i y),\qquad t' = t - \Delta t(x,y,t).$$

- **Pérdida**: minimización de varianza de frames con bins temporales y regularización de suavidad sobre parámetros.

**Uso**:

```bash
# Train with a-parameters trainable, b fixed
python compensate_multiwindow_train_saved_params.py segment.npz \
  --bin_width 50000 --a_trainable --b_default -76.0 \
  --iterations 1000 --smoothness_weight 0.001

# Load pre-trained parameters
python compensate_multiwindow_train_saved_params.py segment.npz \
  --load_params learned_params.npz
```

**Argumentos Clave**:

- `--a_trainable` / `--a_fixed`: Controla el entrenamiento de parámetro a (por defecto: fijo).
- `--b_trainable` / `--b_fixed`: Controla el entrenamiento de parámetro b (por defecto: entrenable).
- `--num_params 13`: Número de parámetros de frontera.
- `--temperature 5000`: Temperatura sigmoide para ventanas suaves.
- `--smoothness_weight 0.001`: Peso de regularización.
- `--load_params file.npz`: Carga parámetros guardados.
- `--chunk_size 250000`: Tamaño de bloque de procesamiento eficiente en memoria.

### 3. Visualización: `visualize_boundaries_and_frames.py`

**Objetivo**: Mostrar parámetros aprendidos y enseñar mejoras cualitativas.

**Características**:

- Superposiciones de parámetros en proyecciones $x\text{–}t$ y $y\text{–}t$.
- Comparativas de frames con bins temporales (original vs. compensado).
- Análisis de ventana deslizante (bins de 50 ms y 2 ms).
- Mapeo de longitud de onda para visualización espectral.

**Uso**:

```bash
python visualize_boundaries_and_frames.py segment.npz \
  --sample_rate 0.1 --wavelength_min 380 --wavelength_max 680
```

### 4. Comparación Acumulativa: `visualize_cumulative_compare.py`

**Objetivo**: Comparar medias acumulativas en pasos de 2 ms con medias por bins deslizantes.

**Descripción Matemática**:

- **Medias acumulativas**:
  $$F(T) = \frac{1}{HW}\sum_{t < T}\text{events}(t).$$

- **Medias deslizantes**: conteo de eventos en $[T-\Delta,\,T)$ dividido por $H \times W$.

- **Relación** (derivada por diferencia finita):
  $$\Delta F(T) \approx \frac{F(T) - F(T-\Delta)}{\Delta}.$$

**Uso**:

```bash
python visualize_cumulative_compare.py segment.npz \
  --sensor_width 1280 --sensor_height 720 \
  --sample_label "My Dataset"
```

## Herramientas Adicionales

### Aplicación GUI: `scan_compensation_gui_cloud.py`

GUI completa para compensación de escaneo con visualización espectral 3D.

**Características**:

- Ajuste interactivo de parámetros.
- Progreso de optimización en tiempo real.
- Visualización 3D mapeada por longitud de onda.
- Exportación de resultados y parámetros.

**Uso**:

```bash
python scan_compensation_gui_cloud.py
```

### Sistema de Doble Cámara (ruta actual)

Sistema de grabación sincronizada para cámaras de eventos y de frames:

- `ImagingGUI/DualCamera_separate_transform.py`

**Características**:

- Grabación simultánea de eventos y frames.
- Vista previa en tiempo real con transformaciones.
- Controles de ventana siempre en primer plano.
- Ajuste de parámetros durante la grabación.

### Utilidades ENVI hiperespectrales

Scripts del repositorio para visualización de cubos ENVI, extracción ROI y preprocesado de visualización:

- `show_envi_spectrum_gui.py`
- `scripts/hs_to_rgb.py`
- `scripts/envi_export_frames.py`
- `scripts/envi_crop_by_roi.py`
- `scripts/hs_gradient_wavelength.py`
- `scripts/cellpose_roi.py`
- `scripts/cellpose_simple_mask.py`
- `scripts/roi_template_match.py`

Punto de entrada típico:

```bash
python show_envi_spectrum_gui.py
```

### Control de Motor Arduino (referencia de ruta heredada conservada)

El README original referenciaba esta ruta de sketch de firmware:

- `rotor/step42_with_key_int/step42_with_key_int.ino`

La estructura actual del repositorio incluye notas de firmware en:

- `firmware/README.md`

Esta discrepancia de rutas se conserva aquí de forma intencional; si tienes carpetas de sketch rotor en otra rama/checkout local, continúa usando esas rutas.

Las capacidades heredadas documentadas de este sketch incluyen:

- Control preciso de ángulo con microstepping.
- Perfiles de aceleración/desaceleración.
- Integración de finales de carrera.
- Funcionalidad de autocentrado.

## Compensación Turbo Multi-Scan

Cuando tienes múltiples escaneos unidireccionales (Forward/Backward) del mismo barrido, puedes fusionarlos y ejecutar el entrenador probado sobre un único flujo de eventos combinado usando `compensate_multiwindow_turbo.py`.

### Qué hace

- Acepta un segmento, una lista explícita o un directorio completo de segmentos.
- Para escaneos Backward, invierte polaridad y revierte tiempo antes de fusionar:
- Si la polaridad `p ∈ {0,1}`: `p := 1 − p`; luego invierte el tiempo dentro del escaneo.
- Si la polaridad `p ∈ {−1,1}`: `p := −p`; luego invierte el tiempo dentro del escaneo.
- Concatena escaneos en una línea de tiempo continua (con una separación de `1 μs` entre escaneos) y llama internamente a `compensate_multiwindow_train_saved_params.py`.

### Uso

```bash
# Merge all scans (Forward+Backward) from a segments folder and train at 5 ms
python compensate_multiwindow_turbo.py \
  --segments-dir path/to/.../_segments \
  --include all --sort name \
  --bin-width 5000 \
  -- --a_trainable --iterations 1000 --smoothness_weight 0.001 --chunk_size 250000 --visualize --plot_params

# Reuse learned params and just render at 10 ms (fast, no training)
python compensate_multiwindow_turbo.py \
  --segments-dir path/to/.../_segments \
  --include all --sort time \
  --bin-width 10000 \
  --load-params path/to/learned_params.npz \
  -- --visualize --plot_params

# Only Forward scans
python compensate_multiwindow_turbo.py \
  --segments-dir path/to/.../_segments \
  --include forward --sort time \
  --bin-width 5000 \
  -- --a_trainable --iterations 1000 --smoothness_weight 0.001 --chunk_size 250000
```

### Opciones

- `--segment`, `--segments`, `--segments-dir`: elige tu conjunto de entrada.
- `--include {all|forward|backward}`: filtra por dirección del escaneo.
- `--sort {name|time}`: orden natural por nombre de archivo o por `start_time` del NPZ.
- `--bin-width <μs>`: se reenvía al entrenador base.
- `--load-params`: reutiliza parámetros guardados (omite entrenamiento y regenera salidas rápido con nuevos anchos de bin).
- `--extra ...` después de `--`: cualquier flag adicional se reenvía al entrenador base.

### Consejo de escalado de velocidad

Si tu escaneo es `N×` más rápido que la línea base, reduce `--bin-width` por el mismo factor (por ejemplo, línea base `50 ms` -> `10×` más rápido -> `5 ms`: `--bin-width 5000`). Puedes entrenar una vez (por ejemplo, `5 ms`) y luego usar `--load-params` para regenerar rápidamente resultados a `10 ms` sin reentrenar.

## Gestión de Parámetros

El sistema soporta funcionalidad completa de guardado/carga de parámetros.

### Formatos de Guardado

- **NPZ**: Formato binario para carga rápida.
- **JSON**: Legible por humanos con metadatos.
- **CSV**: Compatible con Excel para inspección manual.

### Carga de Parámetros

```bash
# Load any supported format
python compensate_multiwindow_train_saved_params.py segment.npz \
  --load_params learned_params.npz

# or --load_params learned_params.json
# or --load_params learned_params.csv
```

### Archivos de Parámetros

Los archivos se nombran automáticamente con el número de parámetros, por ejemplo: `*_learned_params_n13.*`.

## Optimización de Memoria

El sistema usa procesamiento por bloques de forma transversal:

| Elemento | Detalle |
|---|---|
| Tamaño de bloque | `250000` eventos por defecto (configurable) |
| Eficiente en memoria | Procesa datasets grandes sin desbordar la GPU |
| Varianza unificada | Mantiene flujo de gradiente correcto para aprendizaje |
| Seguimiento de progreso | Actualizaciones de procesamiento en tiempo real |

## Estructura de Salida

```text
project/
├── data/
│   ├── recording.raw                    # Original RAW file
│   ├── recording_segments/              # Segmented scans
│   │   ├── Scan_1_Forward_events.npz
│   │   ├── Scan_2_Backward_events.npz
│   │   └── ...
│   ├── learned_params_n13.npz          # Trained parameters
│   ├── learned_params_n13.json
│   ├── learned_params_n13.csv
│   └── visualization_20240115_143022/  # Results
│       ├── events_with_params.png
│       ├── sliding_frames_*.npz
│       ├── frame_means_wavelength.png
│       └── time_binned_frames/         # Individual frames
```

### Artefactos Generados Típicos

| Patrón de artefacto | Producido por | Por qué importa |
|---|---|---|
| `*_segments/Scan_*_events.npz` | Segmentación | Entradas canónicas por escaneo para entrenamiento/visualización |
| `*learned_params_n13.npz` (y `.json`, `.csv`) | Entrenador de compensación | Reutilización de parámetros, reproducibilidad e inspección |
| `visualization_YYYYmmdd_HHMMSS/` | Scripts de visualización / modo visual del entrenador | Mantiene salidas de ejecución aisladas por marca de tiempo |
| `events_with_params.png` y gráficas frame/acumulativas | Scripts de visualización | Validación cualitativa de efectos de compensación |

## Ejemplos de Configuración

### Compensación de Alta Precisión

```bash
python compensate_multiwindow_train_saved_params.py segment.npz \
  --num_params 21 --temperature 3000 --iterations 2000 \
  --a_trainable --b_trainable --boundary_trainable \
  --smoothness_weight 0.0001 --chunk_size 100000
```

### Procesamiento Rápido

```bash
python compensate_multiwindow_train_saved_params.py segment.npz \
  --num_params 7 --iterations 500 --chunk_size 500000 \
  --a_fixed --b_default -76.0
```

### Memoria Limitada

```bash
python compensate_multiwindow_train_saved_params.py segment.npz \
  --chunk_size 50000 --bin_width 100000
```

## Mapeo de Longitud de Onda

El sistema soporta visualización espectral mapeando evolución temporal a longitud de onda:

```python
# Linear mapping: time -> wavelength
wavelength = wavelength_min + (t_normalized / t_max) * (wavelength_max - wavelength_min)
```

**Rango por Defecto**: $380\text{–}680~\text{nm}$ (configurable).

## Consejos y Buenas Prácticas

### Selección de Parámetros

- **Microstepping**: Usa `32×` para movimiento suave (Arduino).
- **Ancho de Bin**: Comienza con `50 ms` para optimización, `2 ms` para análisis.
- **Temperatura**: Valores altos (alrededor de `5000`) para fronteras más suaves.
- **Suavidad**: `0.001` proporciona buena regularización.

### Gestión de Memoria

- **Memoria GPU**: Usa procesamiento por bloques con tamaño de bloque apropiado.
- **Conteo de Eventos**: Se recomienda `> 10^6` eventos para aprendizaje estable.
- **Iteraciones**: `1000` iteraciones suelen ser suficientes.

### Organización de Archivos

- Mantén archivos RAW y segmentos en el mismo directorio.
- Los archivos de parámetros se detectan automáticamente por convención de nombres.
- Usa prefijos de nombre descriptivos para una salida organizada.

## Notas de Desarrollo

- `versions.md` describe eras históricas del proyecto y la justificación de migraciones.
- `.githooks/pre-commit` bloquea commits sobredimensionados/binarios y tipos de archivo no código/documentación.
- `scripts/setup_hooks.sh` establece `core.hooksPath` a `.githooks`.
- `versions/05_archive_code_variants/` almacena variantes antiguas de scripts para mantener enfocado el tooling de nivel raíz.

### Notas de Flujo para Desarrolladores

- Prioriza `scripts/run_scan_pipeline.sh` para ejecuciones base reproducibles y luego pasa a ajuste por script.
- Trata las rutas bajo `comparisons/` como `outputs_root/`, `reference_*` y `align_*` como espacios mixtos de análisis/histórico; evita asumir que son fixtures de prueba mínimos.
- Al agregar scripts nuevos, mantén los entrypoints raíz detectables desde este README y enlaza documentación relacionada (`QUICKSTART.md`, READMEs de submódulos).

Deriva conocida de documentación (conservada intencionalmente para contexto de compatibilidad retroactiva):

- Algunos documentos antiguos mencionan `sync_image_system/` o `dual_camera_gui.py`; el checkout actual contiene `ImagingGUI/DualCamera_separate_transform.py` y directorios SDK.
- `ImagingGUI/README.md` aún referencia `pip install -r requirements.txt`, pero no hay `requirements.txt` en la raíz en este checkout.
- `firmware/README.md` referencia varias subcarpetas de sketches Arduino que no están presentes en este checkout.
- `versions.md` menciona nombres de scripts heredados que difieren de los nombres de scripts actuales en raíz.
- `i18n/` actualmente incluye todos los archivos enlazados en la barra de idioma (`ar`, `de`, `es`, `fr`, `ja`, `ko`, `ru`, `vi`, `zh-Hans`, `zh-Hant`); mantén sincronizados archivos raíz y traducidos al editar encabezados/secciones.

## Solución de Problemas

| Síntoma | Causa probable | Acción |
|---|---|---|
| Errores de carga de parámetros | Incompatibilidad en conteo de parámetros | Asegura que `--num_params` coincida con el archivo guardado |
| OOM / presión de memoria | Bloque demasiado grande o bins demasiado finos | Reduce `--chunk_size` y/o incrementa `--bin_width` |
| Calidad de compensación débil | Entrenamiento insuficiente o mala segmentación | Incrementa `--iterations`, habilita parámetros entrenables, verifica segmentación |
| No se generan archivos segmentados | Problema de RAW/SDK/flag | Confirma ruta RAW, configuración de Metavision y `--segment_events` |
| Argumentos del wrapper turbo ignorados | Sintaxis de reenvío incorrecta | Pasa argumentos del entrenador después de `--` (o usa `--extra`) |
| Problemas de GUI | Incompatibilidad Tkinter/backend o SDK | Verifica backend GUI y disponibilidad del SDK de cámara |

Lista ampliada de solución de problemas (conservada para escaneo rápido):

- **Errores de carga de parámetros**: Asegura que `--num_params` sea compatible con el archivo de parámetros cargado.
- **OOM / presión de memoria**: Reduce `--chunk_size` y/o incrementa `--bin_width`.
- **Calidad de compensación débil**: Incrementa `--iterations`, habilita parámetros entrenables (`--a_trainable`, `--b_trainable`, opcionalmente `--boundary_trainable`) y verifica la calidad de segmentación.
- **No se generan archivos segmentados**: Confirma ruta RAW, disponibilidad del lector Metavision y que se pasó `--segment_events`.
- **Paso de argumentos del wrapper turbo**: Coloca los argumentos del entrenador después de `--` (o usa `--extra`).
- **Problemas de GUI**: Verifica soporte de backend Tkinter y disponibilidad del SDK de cámara en tu plataforma.

## Hoja de Ruta

- Mejorar reproducibilidad de dependencias/bootstrap (`requirements.txt` o lockfile de entorno).
- Consolidar nombres de scripts heredados y referencias de rutas en toda la documentación.
- Expandir esquemas de dataset documentados y convenciones esperadas de campos NPZ.
- Añadir pruebas tipo regresión para segmentación/compensación con datos fixture pequeños.
- Continuar integrando salidas de análisis con calidad de publicación desde pipelines `align_*`.
- Mantener sincronizados el README raíz y todas las variantes existentes `i18n/README.*.md` a medida que evolucionen las secciones.

## Cita

Si este repositorio te resulta útil en tu investigación, por favor cita el artículo de Optica:

```bibtex
@article{chen2026self,
  title   = {Self-calibrated neuromorphic hyperspectral derivative imaging},
  author  = {Chen, Rongzhou and Wang, Chutian and Li, Yuxing and Cao, Yuqing and Zhu, Shuo and Lam, Edmund},
  journal = {Optica},
  volume  = {13},
  number  = {4},
  pages   = {587--590},
  year    = {2026},
  publisher = {Optica Publishing Group},
  doi     = {10.1364/OPTICA.585766}
}
```

## Agradecimientos

- Artículo publicado en Optica y materiales de difusión asociados al proyecto.
- Colaboradores de hardware y software a lo largo de la evolución del repositorio capturada en `versions/` y tooling archivado.
- Apoyo de la comunidad mediante GitHub Sponsors y canales asociados al proyecto.

## Licencia

Este proyecto se publica bajo la Licencia MIT. Consulta [`LICENSE`](../LICENSE) para más detalles.

## Contribuciones

Las contribuciones son bienvenidas.

- Empieza por los scripts existentes y el estilo de documentación actual.
- Mantén ejemplos de línea de comandos reproducibles con rutas del repositorio cuando sea posible.
- Si agregas datasets/salidas grandes, asegúrate de respetar las políticas de `.githooks/pre-commit`.

Nota: no hay un `CONTRIBUTING.md` dedicado en este checkout. Si hace falta, abre un issue o envía un PR con el flujo de contribución que propones.

## Soporte / Patrocinio

| Canal | Enlace | Uso |
|---|---|---|
| GitHub Sponsors | https://github.com/sponsors/lachlanchen | Soporte continuo del proyecto |
| Sitio del proyecto | https://lazying.art | Actualizaciones del proyecto y enlaces del ecosistema |
| Chat comunitario | https://chat.lazying.art | Discusión en comunidad |
| Página adicional del creador | https://onlyideas.art | Contenido relacionado de creador/investigación |
| Página de compra del kit central | https://lazying.art/openhi-kit.html | Kit inicial de hardware para flujo OpenHI |
| Código promocional | `OPTICA` | 30% de descuento (como se documentó arriba) |

### Alcance del Soporte

| Tipo de soporte | Mejor canal |
|---|---|
| Financiación y sostenibilidad | GitHub Sponsors |
| Ecosistema de construcción/compra | Página del kit OpenHI en `lazying.art` |
| Solución comunitaria de problemas | `chat.lazying.art` |
| Actualizaciones generales del proyecto | `lazying.art` y páginas del creador |

---

### Notas

- 📌 Este README conserva notas de rutas heredadas donde la evolución del repositorio introdujo deriva de nombres/diseño.
- 🔒 Si hay dudas sobre referencias antiguas, el texto se conserva intencionalmente en lugar de eliminarse.

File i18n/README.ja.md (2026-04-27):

[English](../README.md) · [العربية](README.ar.md) · [Español](README.es.md) · [Français](README.fr.md) · [日本語](README.ja.md) · [한국어](README.ko.md) · [Tiếng Việt](README.vi.md) · [中文 (简体)](README.zh-Hans.md) · [中文（繁體）](README.zh-Hant.md) · [Deutsch](README.de.md) · [Русский](README.ru.md)

# Self-Calibrated Neuromorphic Hyperspectral Imaging (OpenHI)











> [!NOTE]
> このチェックアウトにおける i18n 状態: `ar`, `es`, `fr`, `ja`, `ko` が `i18n/` に存在します。追加言語のリンクは、今後の翻訳拡充との互換性のために維持しています。

回折格子などの分散照明を用いたイベントカメラから、スペクトルを再構成するための包括的パイプラインです。システムは強度変化イベント $e = (x, y, t, p)$ を記録し、$p \in \{-1, +1\}$ は対数強度変化の極性を表します。さらにイベントストリームから走査タイミングと校正メタデータ（"auto info"）を自動推定します。

<p align="center">
  Device setup
  Acquisition GUI
</p>

*左: モーター駆動の格子照明アームと垂直検出スタックを備えたモジュール式透過顕微鏡。右: セグメンテーション、補償、再構成をリアルタイム監視するデータ取得 GUI。*

## At a Glance

| Item | Details |
|---|---|
| Core idea | イベントストリームに基づく自己校正型ハイパースペクトル微分イメージング |
| Main stages | `segment_robust_fixed.py` -> `compensate_multiwindow_train_saved_params.py` -> 可視化スクリプト群 |
| Hardware docs in repo | `3D/`, `PCB/`, `firmware/`, `BOM/` |
| Desktop tools | `scan_compensation_gui_cloud.py`, `ImagingGUI/DualCamera_separate_transform.py` |
| Canonical paper | [Optica Open preprint (DOI: 10.1364/opticaopen.30739151)](https://doi.org/10.1364/opticaopen.30739151) |
| i18n in this checkout | `README.ar.md`, `README.es.md`, `README.fr.md`, `README.ja.md`, `README.ko.md` |

> [!TIP]
> Optica Open にプレプリント公開された論文 [Self-calibrated neuromorphic hyperspectral imaging](https://doi.org/10.1364/opticaopen.30739151) のコア開発キット（カメラ、チューブレンズ、光学定盤を除く）は以下から購入できます:
> - https://lazying.art/openhi-kit.html
> - 30% オフのプロモーションコード: `OPTICA`

## Contents

- [At a Glance 📌](#at-a-glance)
- [Overview 🔭](#overview)
- [Features ✨](#features)
- [Repository Map 🗺️](#repository-map)
- [Project Structure 📁](#project-structure)
- [Quick Start (5-Min Path) ⚡](#quick-start-5-min-path)
- [Prerequisites 🧰](#prerequisites)
- [Installation ⚙️](#installation)
- [Usage 🚀](#usage)
- [Internationalization 🌍](#internationalization)
- [Configuration 🎛️](#configuration)
- [Examples 🧪](#examples)
- [Bill of Materials (Core Module) 🧾](#bill-of-materials-core-module)
- [Core Scripts 🧠](#core-scripts)
- [Additional Tools 🛠️](#additional-tools)
- [Turbo Multi-Scan Compensation ⚡](#turbo-multi-scan-compensation)
- [Parameter Management 💾](#parameter-management)
- [Memory Optimization 🧱](#memory-optimization)
- [Output Structure 📦](#output-structure)
- [Configuration Examples 🧩](#configuration-examples)
- [Wavelength Mapping 🌈](#wavelength-mapping)
- [Tips and Best Practices ✅](#tips-and-best-practices)
- [Development Notes 🧭](#development-notes)
- [Troubleshooting 🩺](#troubleshooting)
- [Roadmap 🛣️](#roadmap)
- [Citation 📎](#citation)
- [Acknowledgements 🙏](#acknowledgements)
- [License 📄](#license)
- [Contributing 🤝](#contributing)
- [Support / Sponsor 💖](#support--sponsor)

## Overview

照明が時間とともに波長方向へ掃引されると、イベントストリームは分散軸に沿った基礎スペクトルの時間微分を符号化します。

```text
RAW event recording
   -> scan timing segmentation (F/B passes)
   -> multi-window time-warp compensation
   -> frame/cumulative/wavelength diagnostics
```

このパイプラインは次の 3 段階で構成されます。

| Stage | Purpose | Primary script(s) |
|---|---|---|
| 1. Segment | 走査タイミングを検出し、記録を Forward/Backward パスに分割 | `segment_robust_fixed.py` |
| 2. Compensate | 走査起因の時間傾きを除去するための区分線形 time-warp を推定 | `compensate_multiwindow_train_saved_params.py` |
| 3. Visualize | 学習済み境界を重畳し、補償前後の時間ビン化フレームを比較 | `visualize_boundaries_and_frames.py`, `visualize_cumulative_compare.py` |

このリポジトリには、ハードウェア資産、取得 GUI コード、`versions/` 配下の実験アーカイブ分岐も含まれています。

## Features

- RAW からスペクトルまでのイベント処理をエンドツーエンドで実行。
- 走査周期の自動/手動検出と Forward/Backward セグメンテーション。
- 学習可能/固定パラメータモードを備えたマルチウィンドウ補償。
- `NPZ`、`JSON`、`CSV` 形式でのパラメータ保存/読み込み。
- 学習反復を高速化するマルチスキャン統合ワークフロー（`compensate_multiwindow_turbo.py`）。
- 境界、ビン化フレーム、累積曲線、重み付き診断の可視化スイート。
- ハードウェア文書: BOM、PCB、3D パーツ、ファームウェアノート。
- イベント/フレームカメラ同期構成の取得ユーティリティ。

| Category | Included capabilities |
|---|---|
| Signal processing | セグメンテーション、周期検出、time-warp 補償 |
| Optimization | 学習可能/固定パラメータ、平滑化制御、チャンク学習 |
| Outputs | 可視化重畳、累積比較、波長マッピング診断 |
| Platform assets | ハードウェア設計ファイル、ファームウェアノート、GUI ツール、履歴アーカイブ |

## Repository Map

主要なハードウェア資産は、すぐ参照できるようコードと同じリポジトリに配置しています。

| Area | Path |
|---|---|
| 3D-printed parts | [`3D/`](3D/) |
| PCB layouts | [`PCB/`](PCB/) |
| Microcontroller firmware | [`firmware/`](firmware/) |
| Acquisition UI (desktop) | [`ImagingGUI/`](ImagingGUI/) |
| Experiment/data references | [`reference_spectrum_2835/`](reference_spectrum_2835/), [`reference_spectrum_lumileds/`](reference_spectrum_lumileds/), [`references/`](references/) |
| Alignment analysis | [`align_background_vs_reference_code/`](align_background_vs_reference_code/), [`align_data_vs_filter_code/`](align_data_vs_filter_code/) |

## Project Structure

```text
OpenHI/
├── README.md
├── QUICKSTART.md
├── LICENSE
├── versions.md
├── 3D/
├── BOM/
├── PCB/
├── firmware/
├── ImagingGUI/
├── scripts/
├── segment_robust_fixed.py
├── compensate_multiwindow_train_saved_params.py
├── compensate_multiwindow_turbo.py
├── compensate_multiwindow*.py
├── visualize_boundaries_and_frames.py
├── visualize_cumulative_compare.py
├── visualize_cumulative_weighted.py
├── scan_compensation_gui_cloud.py
├── show_envi_spectrum_gui.py
├── simple_raw_reader.py
├── align_background_vs_reference_code/
├── align_data_vs_filter_code/
├── alignment_configs/
├── archive_code_variants/
├── outputs_root/
├── reference_filters/
├── reference_spectrum_2835/
├── reference_spectrum_lumileds/
├── references/
├── i18n/
└── versions/
```

## Quick Start (5-Min Path)

環境準備が済んでおり、データセットフォルダに `*event*.raw` がある場合:

```bash
scripts/run_scan_pipeline.sh /path/to/dataset_dir
```

特定の RAW ファイルを強制指定する場合:

```bash
scripts/run_scan_pipeline.sh /path/to/dataset_dir /path/to/recording_event.raw
```

このラッパーは、リポジトリ既定のスクリプトパスと CLI フラグを使って、セグメンテーション、補償学習、可視化をまとめて実行します。

> [!TIP]
> 最初の検証では、まず 1 つのデータセットディレクトリでラッパーを実行し、生成された segment NPZ と可視化出力を確認してから `PIPELINE_*` 変数を調整してください。

## Prerequisites

- Python 3.9+（`ImagingGUI/` 配下の一部 GUI ツールでは Python 3.10+）。
- コア Python パッケージ: `numpy`, `torch`, `matplotlib`。
- 任意だが一般的: `opencv-python`, `pillow`, `cellpose`。
- RAW イベント読み取りワークフロー（`simple_raw_reader.py`、RAW からのセグメンテーション）向けの Metavision SDK / Python バインディング。
- 最適化高速化のため CUDA 対応 PyTorch を推奨。
- RAW 記録および/またはセグメント化済み NPZ ファイルがローカルにあること。

## Installation

現時点でリポジトリルートに固定された環境定義ファイルはありません。推奨セットアップは以下です。

```bash
# create and activate a virtual environment or conda env
python -m venv .venv
source .venv/bin/activate

# install core dependencies
pip install numpy matplotlib torch

# optional tools often used in this repository
pip install opencv-python pillow
# pip install cellpose
```

大容量ファイル管理向けに Git hooks を使う場合:

```bash
bash scripts/setup_hooks.sh
```

## Usage

### Basic Workflow (current root scripts)

```bash
# 1. Segment RAW into 6 scans (Forward/Backward)
python segment_robust_fixed.py \
  data/recording.raw \
  --segment_events \
  --output_dir data/segments/

# 2. Train multi-window compensation
python compensate_multiwindow_train_saved_params.py \
  data/segments/Scan_1_Forward_events.npz \
  --bin_width 50000 \
  --visualize --plot_params --a_trainable \
  --iterations 1000

# 3. Visualize results with boundaries
python visualize_boundaries_and_frames.py \
  data/segments/Scan_1_Forward_events.npz

# 4. Compare cumulative vs multi-bin means
python visualize_cumulative_compare.py \
  data/segments/Scan_1_Forward_events.npz \
  --sensor_width 1280 --sensor_height 720
```

### One-command convenience wrapper

```bash
scripts/run_scan_pipeline.sh /path/to/dataset_dir [raw_file]
```

`scripts/run_scan_pipeline.sh` がサポートする環境変数:

| Variable | Default | Purpose |
|---|---:|---|
| `PIPELINE_ACTIVITY_FRACTION` | `0.90` | Active event window fraction |
| `PIPELINE_BIN_WIDTH` | `50000` | Training bin width in microseconds |
| `PIPELINE_SENSOR_WIDTH` | `1280` | Sensor width for visualization |
| `PIPELINE_SENSOR_HEIGHT` | `720` | Sensor height for visualization |
| `PIPELINE_SAMPLE_RATE` | `0.10` | Event sampling fraction for plotting |
| `PIPELINE_TIME_BIN_US` | `1000` | Segmentation activity-bin size |
| `PIPELINE_SEGMENT_PATTERN` | `Scan_1_Forward_events.npz` | Segment file pattern for downstream scripts |

## Internationalization

リポジトリでは、言語バーの重複を避けるため、各 README の先頭に単一の言語オプション行を配置しています。

`i18n/` で現在利用可能な翻訳ファイル:

- `README.ar.md`
- `README.es.md`
- `README.fr.md`
- `README.ja.md`
- `README.ko.md`

| Language link in nav | File in `i18n/` | Status |
|---|---|---|

将来互換性のため、予定中言語のリンクもトップナビで意図的に保持しています。

## Configuration

各スクリプトで共通して重要な CLI 制御:

### Segmentation (`segment_robust_fixed.py`)

- `--time_bin_us`: マイクロ秒単位のアクティビティビンサイズ。
- `--round_trip_period`: 手動周期（既定 `1688` bins）。
- `--auto_calculate_period`: 自己相関による周期推定。
- `--activity_fraction`: アクティブイベント窓の割合。
- `--manual_start_shift_ms`: 走査開始の手動オフセット。

### Compensation (`compensate_multiwindow_train_saved_params.py`)

- `--num_params`（既定 `13`）, `--temperature`（既定 `5000`）。
- `--a_trainable` / `--a_fixed`, `--b_trainable` / `--b_fixed`, `--boundary_trainable`。
- `--a_default`, `--b_default`。
- `--iterations`, `--learning_rate`, `--smoothness_weight`。
- メモリ制御用 `--chunk_size`。
- 学習済みパラメータ再利用用 `--load_params`。

### Visualization

- `visualize_boundaries_and_frames.py`: `--sample_rate`, `--wavelength_min`, `--wavelength_max`, センサーサイズ引数。
- `visualize_cumulative_compare.py`: センサーサイズ、`--output_dir`, `--sample_label`。
- `visualize_cumulative_weighted.py`: polarity スケール、`--step_us`, `--auto_scale`, `--exp`, `--no_comp`。

## Examples

### Quick start dataset-style commands (from `QUICKSTART.md`)

```bash
python segment_robust_fixed.py \
  led_12v_no_acc_glass/glass/sync_recording_12v_led_no_acc_blank_event_20250804_232556.raw \
  --segment_events \
  --output_dir led_12v_no_acc_glass/glass/

python compensate_multiwindow_train_saved_params.py \
  led_12v_no_acc_glass/glass/sync_recording_12v_led_no_acc_blank_event_20250804_232556_segments/Scan_1_Forward_events.npz \
  --bin_width 50000 \
  --visualize --plot_params --a_trainable \
  --iterations 1000 \
  --b_default 0 \
  --smoothness_weight 0.001

python visualize_boundaries_and_frames.py \
  led_12v_no_acc_glass/glass/sync_recording_12v_led_no_acc_blank_event_20250804_232556_segments/Scan_1_Forward_events.npz
```

### Legacy helper commands retained from historical workflows

```bash
python scanning_alignment_visualization_save.py \
  led_12v_no_acc_glass/glass/sync_recording_12v_led_no_acc_blank_event_20250804_232556_segments/Scan_1_Forward_events.npz \
  --output_dir led_12v_no_acc_glass/glass/sync_recording_12v_led_no_acc_blank_event_20250804_232556_segments/FIXED_visualization

python scanning_alignment_visualization_cumulative_compare.py \
  led_12v_no_acc_glass/glass/sync_recording_12v_led_no_acc_blank_event_20250804_232556_segments/Scan_1_Forward_events.npz \
  --sensor_width 1280 --sensor_height 720 \
  --output_dir led_12v_no_acc_glass/glass/sync_recording_12v_led_no_acc_blank_event_20250804_232556_segments/cumulative_vs_bin2ms \
  --sample_label "led_12v_no_acc_glass Scan_1_Forward"
```

これらの旧コマンドは互換性コンテキストのため意図的に保持しています。このチェックアウトでは、可能な限り現在のルートスクリプトを使用してください。

### Turbo multi-scan training

```bash
python compensate_multiwindow_turbo.py \
  --segments-dir path/to/your_segments \
  --include all --sort name \
  --bin-width 5000 \
  -- --a_trainable --iterations 1000 --smoothness_weight 0.001 --chunk_size 250000 --visualize --plot_params
```

### Reuse learned parameters (skip retraining)

```bash
python compensate_multiwindow_train_saved_params.py segment.npz \
  --load_params learned_params.npz
```

## Bill of Materials (Core Module)

リンク・注釈付き完全版テーブルは [`BOM/core_module.md`](BOM/core_module.md) を参照してください。

### Table S2. Acquisition Time and Cost Comparison Between the Proposed Event-Driven System and a Reference Hyperspectral Camera

| Parameter | Ours | Reference camera |
|---|---|---|
| Acquisition time | ∼585 ms per scan | 300 s per scan |
| Data volume | 18.5 MB | 138 MB |
| Approx. price | ∼3000 USD | 14 000 USD |

### Table S3. Bill of Materials for the Core Scanning Illumination Module
(Excluding event camera and optional 4f validation optics)

| Component | Notes | Cost (USD) | Taobao Link |
|---|---|---:|---|
| Motion control | NEMA42 + TB6600 + Arduino Uno | 15.00 | https://e.tb.cn/h.7FHgkEvoo6tpKTo?tk=QYRFUPRqazE |
| Optics (grating) | Diffraction grating (education grade) | 3.47 | https://e.tb.cn/h.7Fhj16MkrSDHNnE?tk=3Q8dUPRouNw |
| Illumination | 2835 LED (6 CNY / 10 pcs; 0.6 CNY used) | 0.08 | https://e.tb.cn/h.7uubHIVL5diILHl?tk=tzTAUPRr14K |
| Reflector | Folding mirror | 6.25 | https://e.tb.cn/h.7uu1rNNSbgVdS31?tk=PqsxUPRHb32 |
| Electronics | LED PCB (CNY/board; min order 5 pcs) | 1.67 |  |
| Limit switches | Optional, 2 × 8.07 CNY | 2.24 | https://e.tb.cn/h.7FHEKbcgJmc2Ll1?tk=I4FRUP8diRE |
| 3D printing | One-third PLA filament spool (covers all printed parts) | 5.09 | https://e.tb.cn/h.7FhOVWX7SLHvNNf?tk=kOcQUPRJsbo |
| Lens | Plano-convex lens (25.4 mm, 350–700 nm AR) |  | https://e.tb.cn/h.7FSePNYhqt7ITbh?tk=tH8ZUP8i3cC |
| Total | core module | **33.99** |  |

## Core Scripts

### 1. Segmentation: `segment_robust_fixed.py`

**Goal**: 生イベントから走査タイミングを抽出し、6 本の片道スキャン（F, B, F, B, F, B）に分割する。

**Mathematical Description**:

- **Activity signal** (events binned with $\Delta t = 1000~\mu\text{s}$):
  $$a[n] = \left|\{ i \mid t_{\min} + n\Delta t \le t_i < t_{\min} + (n+1)\Delta t \}\right|.$$

- **Active window detection**: イベントの $80\%$ を含む最小連続ウィンドウを見つける。

- **Period estimation**: 自己相関、または手動周期（既定: $1688$ bins）。

- **Reverse-correlation** (timing structure):
  $$R[k] = \sum_{n} a[n]\, a_{\text{rev}}[n+k]$$
  with
  $$a_{\text{rev}}[n] = a[N-1-n].$$

**Usage**:

```bash
# Automatic period detection
python segment_robust_fixed.py recording.raw --segment_events --output_dir segments/

# Manual period (fixed 1688 bins)
python segment_robust_fixed.py recording.raw --segment_events --round_trip_period 1688
```

**Arguments**:

- `--segment_events`: 各スキャンセグメントを NPZ として保存。
- `--round_trip_period 1688`: 手動周期を使用（既定）。
- `--auto_calculate_period`: 手動周期を自己相関推定で上書き。
- `--activity_fraction 0.80`: アクティブ領域として扱うイベント割合。
- `--max_iterations 2`: リファイン反復回数。

### 2. Compensation: `compensate_multiwindow_train_saved_params.py`

**Goal**: マルチウィンドウ区分線形補償により、走査起因の時間せん断を除去する time-warp パラメータを学習する。

**Mathematical Description**:

- **Boundary surfaces**:
  $$T_i(x, y) = a_i x + b_i y + c_i,\quad i=0,\ldots,M-1.$$

- **Soft window memberships**:
  $$m_i = \sigma\!\Big(\frac{t - T_i}{\tau}\Big)\,\sigma\!\Big(\frac{T_{i+1} - t}{\tau}\Big),\qquad w_i = \frac{m_i}{\sum_j m_j + \varepsilon}.$$

- **Interpolated slopes (optional)**:
  $$\alpha_i = \frac{t - T_i}{T_{i+1} - T_i},\quad a_i' = (1-\alpha_i)a_i + \alpha_i a_{i+1},\quad b_i' = (1-\alpha_i)b_i + \alpha_i b_{i+1}.$$

- **Time warp**:
  $$\Delta t(x,y,t) = \sum_i w_i (\tilde{a}_i x + \tilde{b}_i y),\qquad t' = t - \Delta t(x,y,t).$$

- **Loss**: time-binned frame の分散最小化 + パラメータ平滑化正則化。

**Usage**:

```bash
# Train with a-parameters trainable, b fixed
python compensate_multiwindow_train_saved_params.py segment.npz \
  --bin_width 50000 --a_trainable --b_default -76.0 \
  --iterations 1000 --smoothness_weight 0.001

# Load pre-trained parameters
python compensate_multiwindow_train_saved_params.py segment.npz \
  --load_params learned_params.npz
```

**Key Arguments**:

- `--a_trainable` / `--a_fixed`: a パラメータの学習可否（既定: fixed）。
- `--b_trainable` / `--b_fixed`: b パラメータの学習可否（既定: trainable）。
- `--num_params 13`: 境界パラメータ数。
- `--temperature 5000`: soft window 用シグモイド温度。
- `--smoothness_weight 0.001`: 正則化重み。
- `--load_params file.npz`: 保存済みパラメータを読み込み。
- `--chunk_size 250000`: メモリ効率のための処理チャンクサイズ。

### 3. Visualization: `visualize_boundaries_and_frames.py`

**Goal**: 学習済みパラメータを表示し、品質改善を定性的に確認する。

**Features**:

- $x\text{–}t$ と $y\text{–}t$ 投影へのパラメータ重畳。
- 時間ビン化フレーム比較（補償前 vs 補償後）。
- スライディングウィンドウ解析（50 ms と 2 ms ビン）。
- スペクトル可視化のための波長マッピング。

**Usage**:

```bash
python visualize_boundaries_and_frames.py segment.npz \
  --sample_rate 0.1 --wavelength_min 380 --wavelength_max 680
```

### 4. Cumulative Comparison: `visualize_cumulative_compare.py`

**Goal**: 累積 2 ms ステップ平均とスライディングビン平均を比較する。

**Mathematical Description**:

- **Cumulative means**:
  $$F(T) = \frac{1}{HW}\sum_{t < T}\text{events}(t).$$

- **Sliding means**: $[T-\Delta,\,T)$ のイベント数を $H \times W$ で除算。

- **Relationship** (finite-difference derivative):
  $$\Delta F(T) \approx \frac{F(T) - F(T-\Delta)}{\Delta}.$$

**Usage**:

```bash
python visualize_cumulative_compare.py segment.npz \
  --sensor_width 1280 --sensor_height 720 \
  --sample_label "My Dataset"
```

## Additional Tools

### GUI Application: `scan_compensation_gui_cloud.py`

3D スペクトル可視化を備えた、走査補償用のフル GUI アプリケーションです。

**Features**:

- 対話的パラメータ調整。
- 最適化進行のリアルタイム表示。
- 3D 波長マップ可視化。
- 結果とパラメータのエクスポート。

**Usage**:

```bash
python scan_compensation_gui_cloud.py
```

### Dual Camera System (current path)

イベントカメラとフレームカメラの同期記録システム:

- `ImagingGUI/DualCamera_separate_transform.py`

**Features**:

- イベント/フレームの同時記録。
- 変換付きリアルタイムプレビュー。
- 最前面固定ウィンドウ制御。
- 記録中のパラメータ調整。

### Arduino Motor Control (legacy path reference retained)

元の README では以下のファームウェアスケッチパスを参照していました:

- `rotor/step42_with_key_int/step42_with_key_int.ino`

現在のリポジトリ構成では、ファームウェア注記は以下にあります:

- `firmware/README.md`

このパス差異は意図的に保持しています。別ブランチ/ローカルチェックアウトに rotor スケッチフォルダがある場合は、そのパスを継続して使用してください。

このスケッチの旧ドキュメント上の機能は以下です:

- マイクロステップによる高精度角度制御。
- 加減速プロファイル。
- リミットスイッチ統合。
- 自動センタリング機能。

## Turbo Multi-Scan Compensation

同一スイープの片道スキャン（Forward/Backward）が複数ある場合、`compensate_multiwindow_turbo.py` で統合し、単一の結合イベントストリームとして既存トレーナーを実行できます。

### What it does

- 単一セグメント、明示リスト、またはセグメントディレクトリ全体を入力可能。
- Backward スキャンでは、極性反転と時間反転を行ってから統合:
- 極性が `p ∈ {0,1}` の場合: `p := 1 − p`; その後スキャン内時間を反転。
- 極性が `p ∈ {−1,1}` の場合: `p := −p`; その後スキャン内時間を反転。
- 連続タイムライン上でスキャンを連結（スキャン間ギャップ `1 μs`）し、内部で `compensate_multiwindow_train_saved_params.py` を呼び出します。

### Usage

```bash
# Merge all scans (Forward+Backward) from a segments folder and train at 5 ms
python compensate_multiwindow_turbo.py \
  --segments-dir path/to/.../_segments \
  --include all --sort name \
  --bin-width 5000 \
  -- --a_trainable --iterations 1000 --smoothness_weight 0.001 --chunk_size 250000 --visualize --plot_params
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

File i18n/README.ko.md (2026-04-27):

[English](../README.md) · [العربية](README.ar.md) · [Español](README.es.md) · [Français](README.fr.md) · [日本語](README.ja.md) · [한국어](README.ko.md) · [Tiếng Việt](README.vi.md) · [中文 (简体)](README.zh-Hans.md) · [中文（繁體）](README.zh-Hant.md) · [Deutsch](README.de.md) · [Русский](README.ru.md)

# Self-Calibrated Neuromorphic Hyperspectral Imaging (OpenHI)








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

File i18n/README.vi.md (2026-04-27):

[English](../README.md) · [العربية](README.ar.md) · [Español](README.es.md) · [Français](README.fr.md) · [日本語](README.ja.md) · [한국어](README.ko.md) · [Tiếng Việt](README.vi.md) · [中文 (简体)](README.zh-Hans.md) · [中文（繁體）](README.zh-Hant.md) · [Deutsch](README.de.md) · [Русский](README.ru.md)

# Tạo ảnh siêu phổ neuromorphic tự hiệu chuẩn (OpenHI)





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

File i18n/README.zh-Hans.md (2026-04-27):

[English](../README.md) · [العربية](README.ar.md) · [Español](README.es.md) · [Français](README.fr.md) · [日本語](README.ja.md) · [한국어](README.ko.md) · [Tiếng Việt](README.vi.md) · [中文 (简体)](README.zh-Hans.md) · [中文（繁體）](README.zh-Hant.md) · [Deutsch](README.de.md) · [Русский](README.ru.md)
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

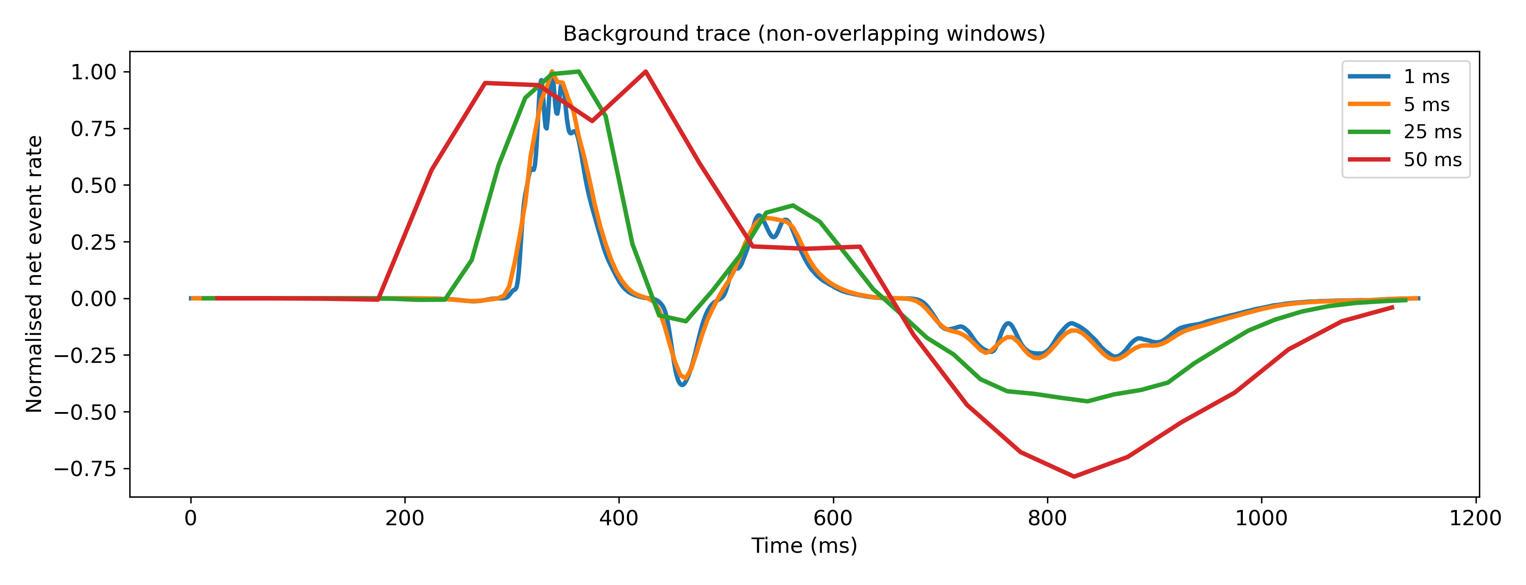
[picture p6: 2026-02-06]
comparisons/align_background_vs_reference_code/publication_20260206_221154/background_trace_multibin_Scan_1_Forward_events.png

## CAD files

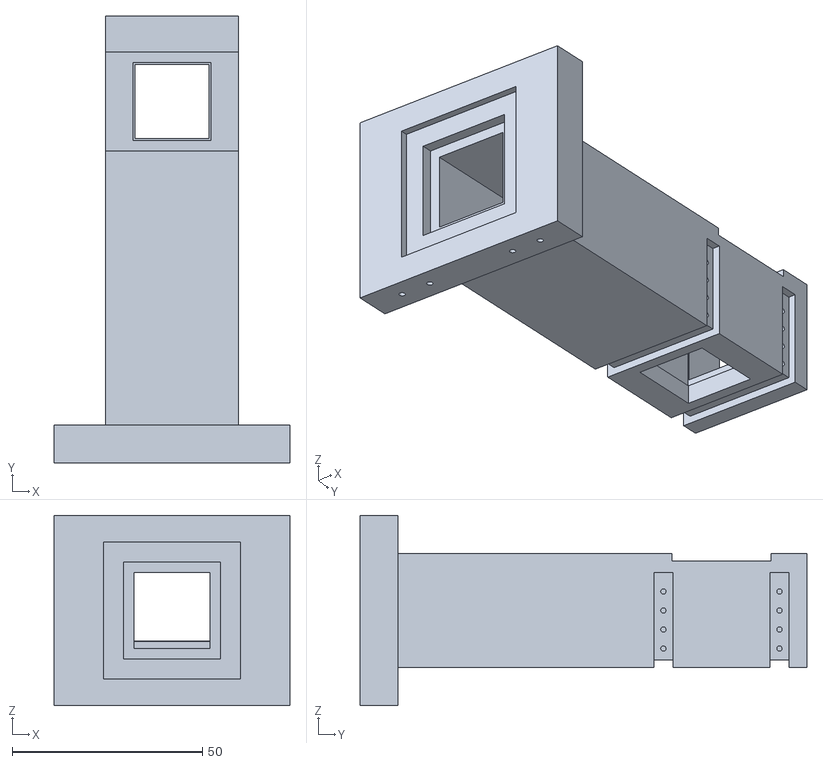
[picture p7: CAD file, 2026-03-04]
3D/OpenHICoreModule3D/Grating & dichroic.stl
62.0 x 117.5 x 50.0

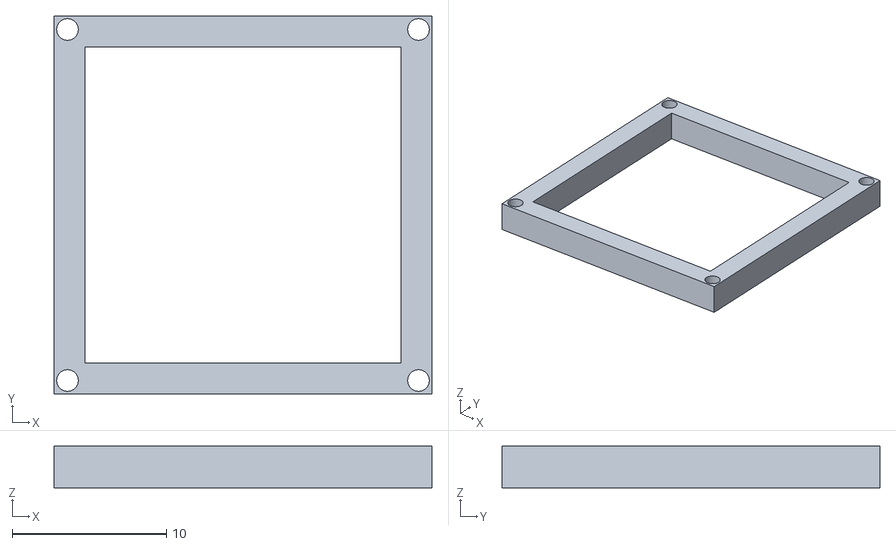
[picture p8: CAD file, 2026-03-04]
3D/Optional4F3D/BS cap.stl
24.5 x 24.5 x 2.70

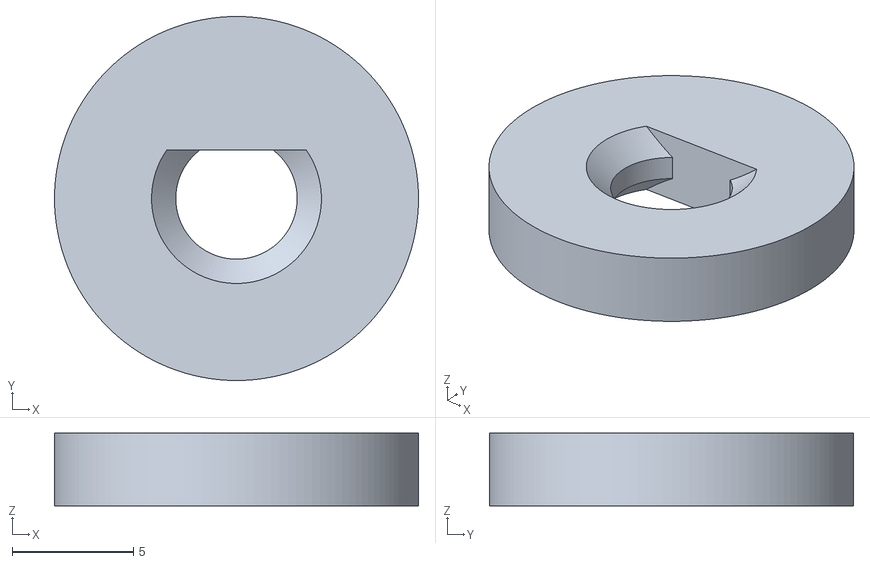
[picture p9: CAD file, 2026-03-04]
3D/OpenHICoreModule3D/Motor cusion.stl
15.0 x 15.0 x 3.00

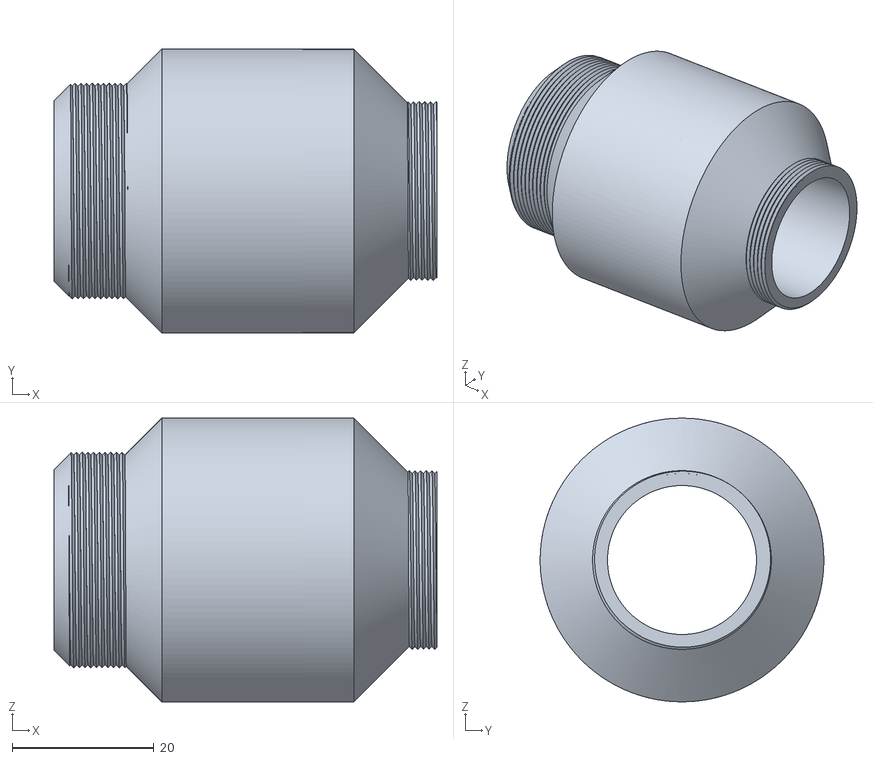
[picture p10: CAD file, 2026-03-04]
3D/Optional4F3D/C.stl
54.0 x 40.0 x 40.0

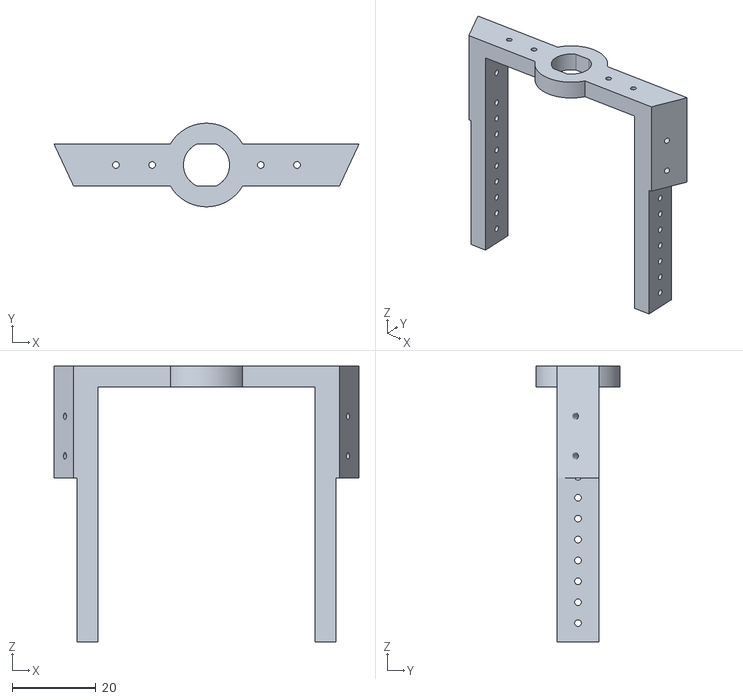
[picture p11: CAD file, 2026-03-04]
3D/OpenHICoreModule3D/Light switch holder.stl
73.0 x 20.0 x 66.0

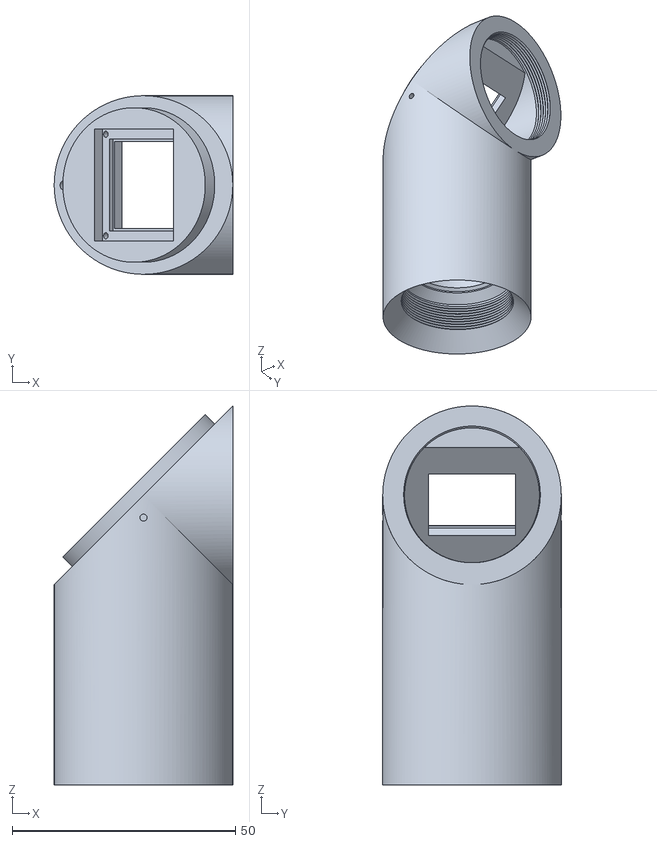
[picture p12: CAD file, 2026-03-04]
3D/Optional4F3D/A+ C + BS.stl
40.0 x 40.0 x 84.9

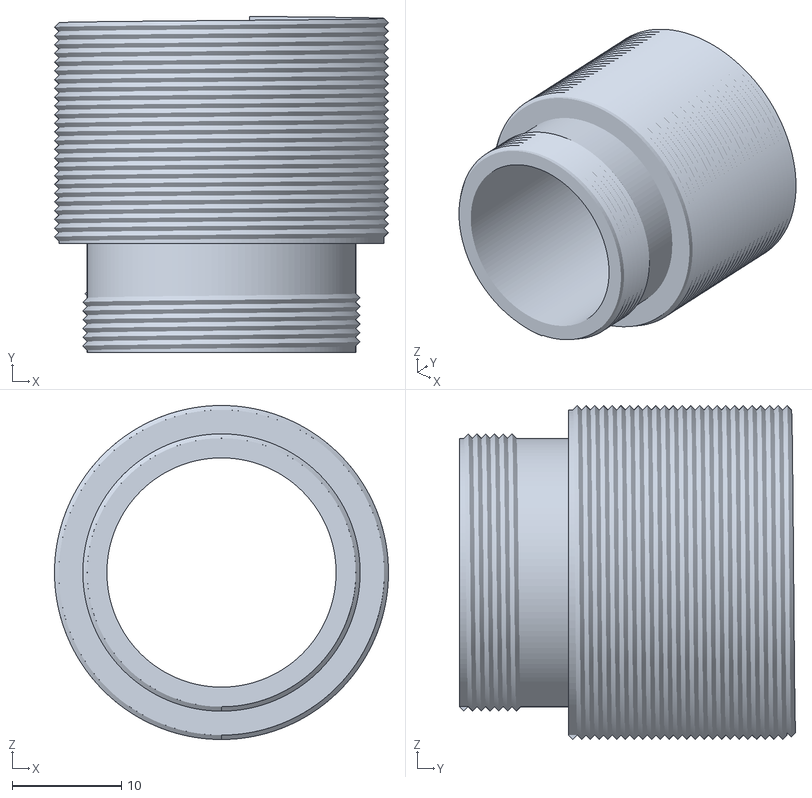
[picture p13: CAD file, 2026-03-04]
3D/OpenHICoreModule3D/Collimator tube.stl
30.6 x 30.8 x 30.6

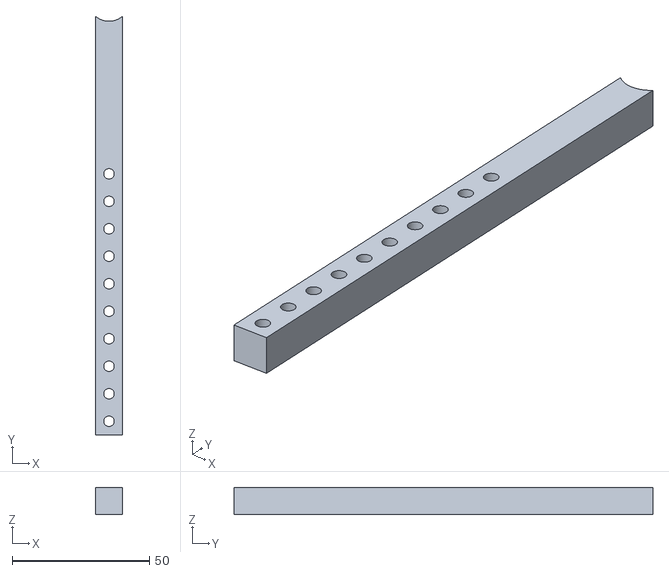
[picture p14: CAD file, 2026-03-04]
3D/OpenHICoreModule3D/Collimator arm FHPLP.stl
10.0 x 152.4 x 10.0

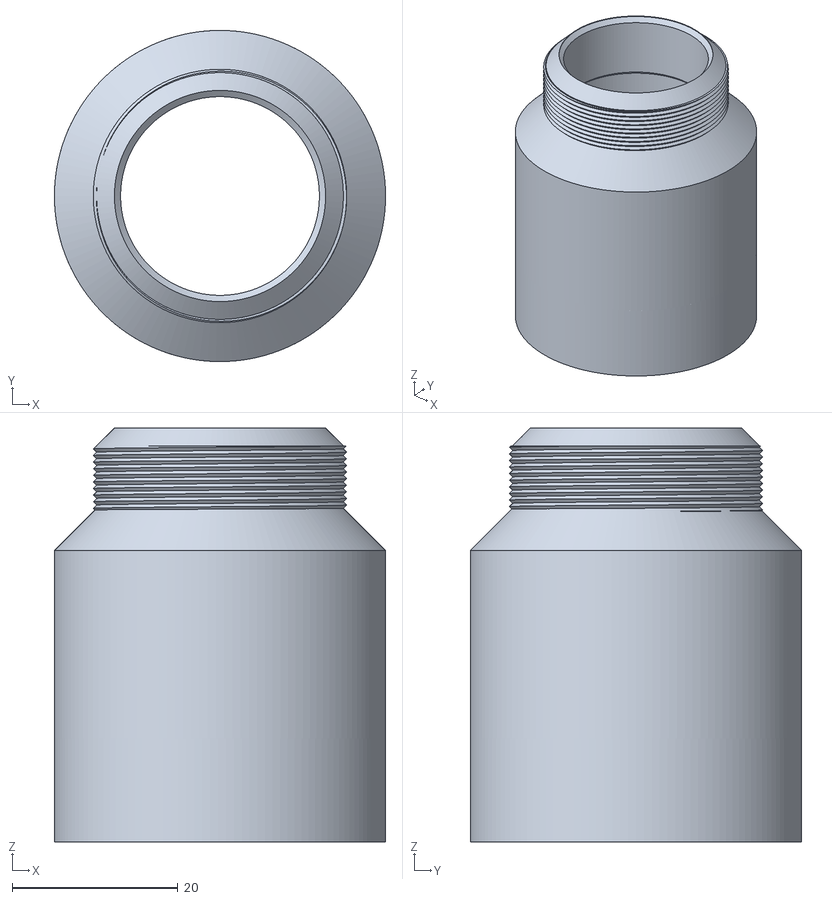
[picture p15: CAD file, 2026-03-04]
3D/Optional4F3D/A.stl
40.0 x 40.0 x 50.0

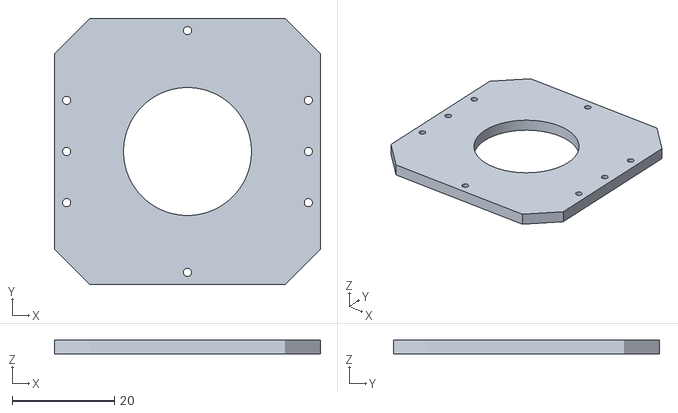
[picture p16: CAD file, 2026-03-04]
3D/OpenHICoreModule3D/Motor lid.stl
52.0 x 52.0 x 2.75

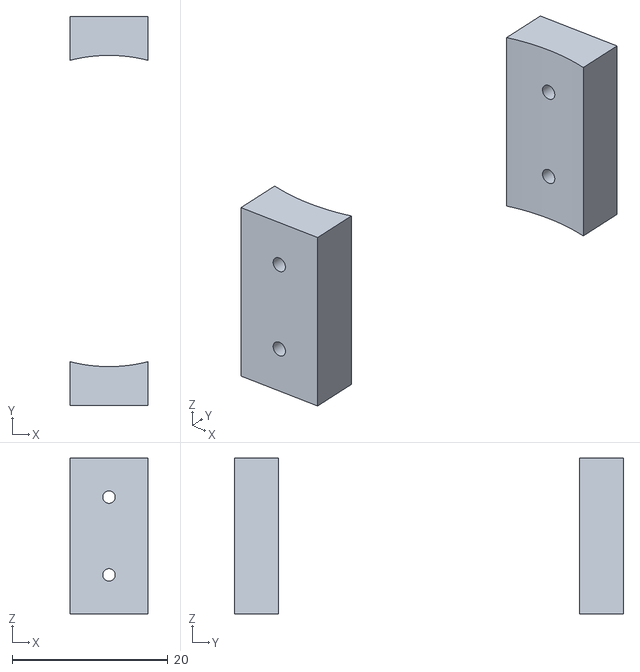
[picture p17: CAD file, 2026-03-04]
3D/Optional4F3D/Locks.stl
10.0 x 50.0 x 20.0

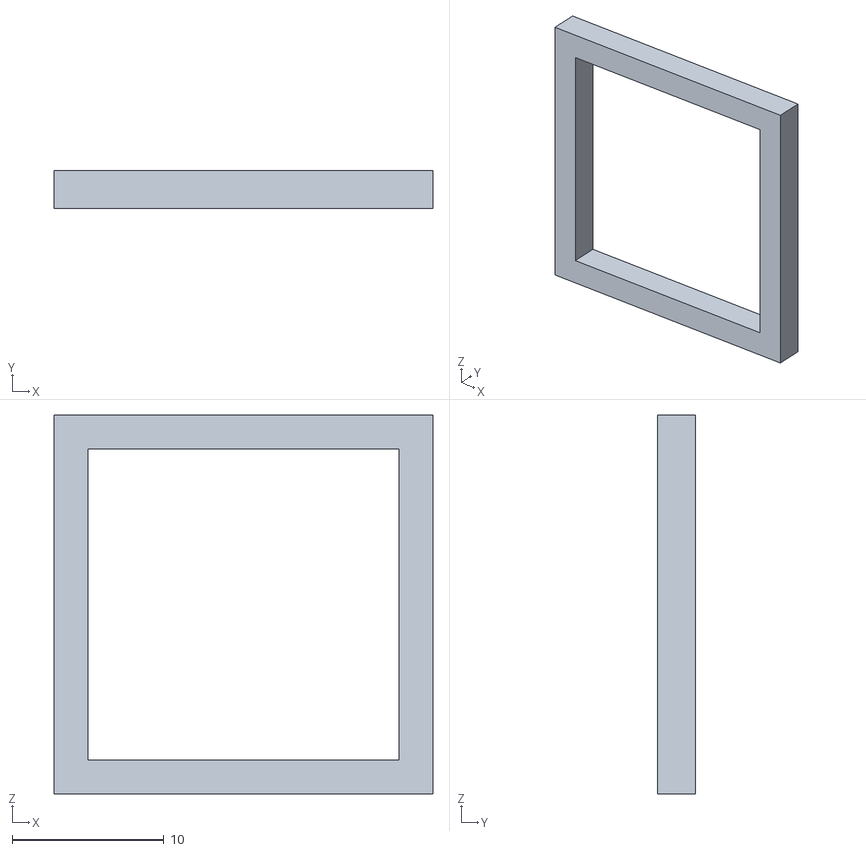
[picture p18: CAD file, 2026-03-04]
3D/OpenHICoreModule3D/Grating fixer.stl
25.0 x 2.50 x 25.0

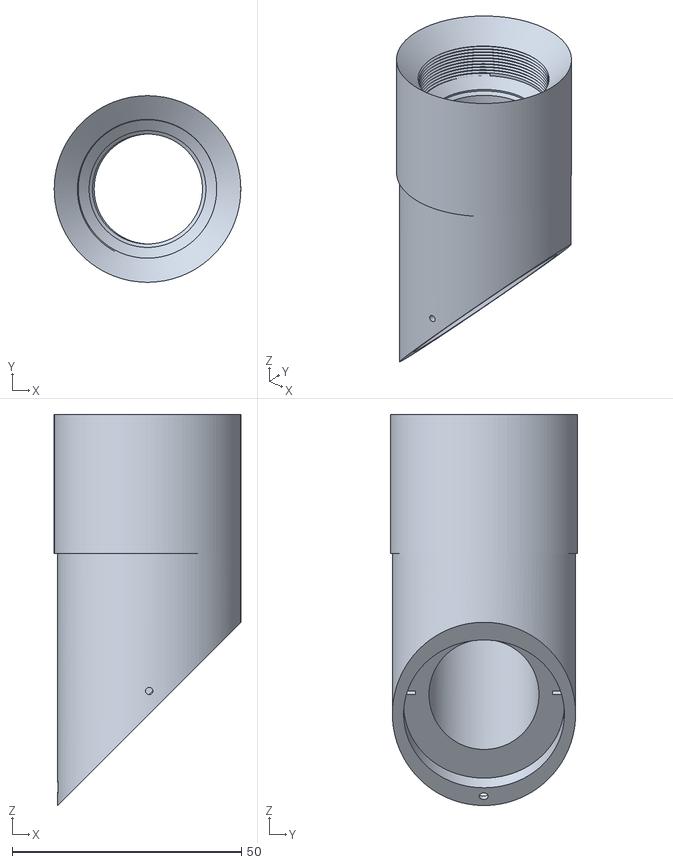
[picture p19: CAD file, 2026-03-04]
3D/Optional4F3D/Lens B holder.stl
40.7 x 40.7 x 85.4

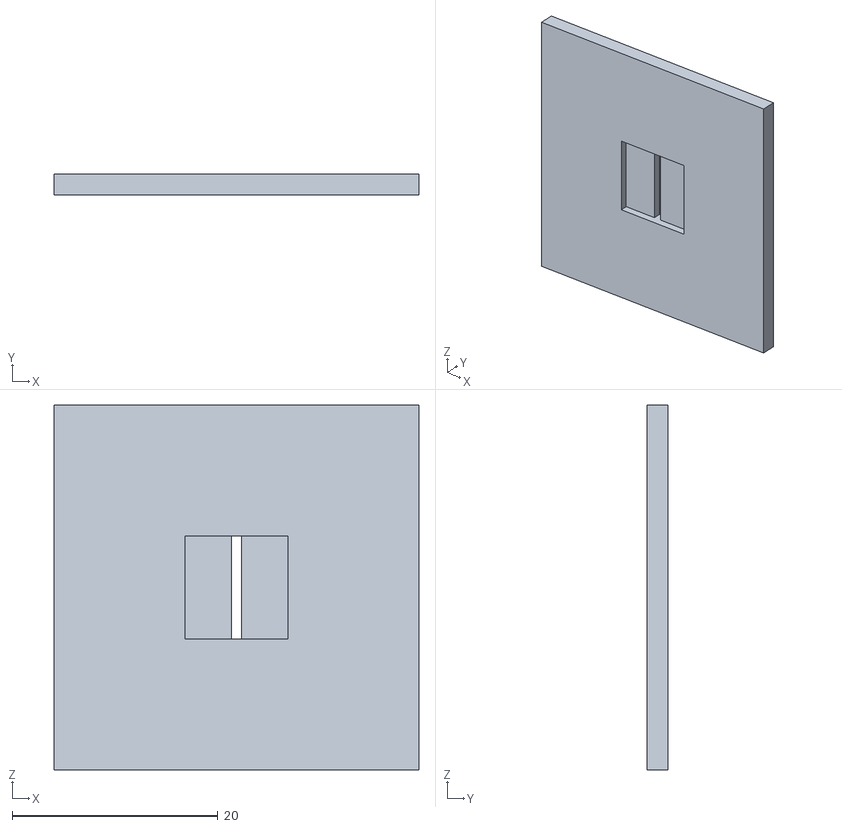
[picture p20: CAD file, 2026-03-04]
3D/OpenHICoreModule3D/Grating cap.stl
35.5 x 2.00 x 35.5

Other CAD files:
3D/Optional4F3D/B.stl
3D/Optional4F3D/Lens C holder.stl
3D/OpenHICoreModule3D/Motor cap.stl
3D/OpenHICoreModule3D/Collimator holder FHPLP.stl
3D/OpenHICoreModule3D/Collimator cap.stl
3D/OpenHICoreModule3D/LED holder.stl
3D/OpenHICoreModule3D/Motor holder.stl
3D/OpenHICoreModule3D/Sensor arm.stl

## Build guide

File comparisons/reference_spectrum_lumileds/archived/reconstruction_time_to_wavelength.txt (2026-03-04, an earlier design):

Compensated reconstruction vs. ground-truth alignment
Neg polarity scale (auto): 1.256329
Reconstruction start (ms): 368.820
Reconstruction end (ms): 865.360
Ground-truth start (nm): 417.036
Ground-truth end (nm): 723.185
Mapping formula (ms → nm):
  λ(t_ms) = 0.616565 * t_ms + 189.634
Where t_ms is compensated time measured relative to the earliest bin.

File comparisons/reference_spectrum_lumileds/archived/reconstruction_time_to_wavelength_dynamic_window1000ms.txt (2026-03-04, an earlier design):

Dynamic sliding-window reconstruction vs. ground-truth alignment
Neg polarity scale (auto): 1.283835
Window width (ms): 1000.000
Reconstruction start (ms): 348.537
Reconstruction end (ms): 841.191
Ground-truth start (nm): 417.036
Ground-truth end (nm): 723.185
Mapping formula (ms → nm):
  λ(t_ms) = 0.621428 * t_ms + 200.445
Where t_ms is the compensated event timeline measured from the first sample.

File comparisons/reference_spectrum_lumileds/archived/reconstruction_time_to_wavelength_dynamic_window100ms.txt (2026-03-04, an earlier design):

Dynamic sliding-window reconstruction vs. ground-truth alignment
Neg polarity scale (auto): 0.100000
Window width (ms): 100.000
Reconstruction start (ms): 338.896
Reconstruction end (ms): 602.768
Ground-truth start (nm): 417.036
Ground-truth end (nm): 723.185
Mapping formula (ms → nm):
  λ(t_ms) = 1.160218 * t_ms + 23.843
Where t_ms is the compensated event timeline measured from the first sample.

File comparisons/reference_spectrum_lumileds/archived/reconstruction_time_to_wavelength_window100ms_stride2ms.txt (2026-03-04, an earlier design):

Sliding-window reconstruction vs. ground-truth alignment
Neg polarity scale (auto): 0.100000
Window width (ms): 100.000
Window stride (ms): 2.000
Reconstruction start (ms): 232.000
Reconstruction end (ms): 508.000
Ground-truth start (nm): 417.036
Ground-truth end (nm): 723.185
Mapping formula (ms → nm):
  λ(t_ms) = 1.109236 * t_ms + 159.693
Where t_ms is the compensated window-centre timeline measured from the earliest window.

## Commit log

2026-02-06 feat(publication): add dual blank+sample panel
2026-02-06 feat(publication): align sample plateau to GT
2026-02-06 feat(publication): add sample wavelength shift
2026-02-06 docs: record dual blank+sample overlay
2026-02-06 feat(publication): auto-shift sample by corr
2026-02-06 feat(background): plot multibin traces
2026-02-06 docs: add multibin background trace note
2026-02-08 docs: add BOM table for core module
2026-02-08 docs: add BOM overview and lens
2026-02-08 docs(bom): add acquisition table and lens link
2026-03-04 chore: add 3D module assets
    [A+ C + BS.stl, A.stl, B.stl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]
2026-03-04 chore: untrack reference_filters
    [NP470_bandpass_470nm.xls, bandpass_500-600nm.xls, bandpass_520nm_10nm_OD3_520F10.xls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]
2026-03-04 chore: move comparison folders under comparisons
    [frame_statistics_spd.csv, frame_statistics_spd_completed.csv, training_log.csv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]
2026-09-09 Link OpenHI reproducibility sample

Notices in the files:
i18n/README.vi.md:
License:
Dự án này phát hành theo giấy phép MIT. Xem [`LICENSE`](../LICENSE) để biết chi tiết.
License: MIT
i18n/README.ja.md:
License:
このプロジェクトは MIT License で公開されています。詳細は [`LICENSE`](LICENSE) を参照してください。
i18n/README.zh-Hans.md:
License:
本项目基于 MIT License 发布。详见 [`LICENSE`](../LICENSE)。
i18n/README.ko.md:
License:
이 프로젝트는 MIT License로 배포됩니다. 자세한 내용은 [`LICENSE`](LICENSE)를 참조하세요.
